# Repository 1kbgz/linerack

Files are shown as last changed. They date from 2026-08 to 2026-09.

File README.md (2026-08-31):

# LineRack

LineRack is a USB-powered audio processor with browser-configurable effect
chains. The repository contains the configurator, Seed3 firmware, hardware
designs, and developer documentation for the working prototype.

LineRack is under active development. The current hardware is suitable for
development and listening tests, not production or safety-critical use.

## Repository map

| Path | Contents |
| --- | --- |
| `src/` | React configurator, simulator, and documentation site |
| `firmware/` | Seed3 diagnostics and composite USB Audio/WebHID firmware |
| `firmware/dsp/` | Host-tested signal-processing implementation |
| `firmware/usb/` | USB transport, preset storage, display, and protocol logic |
| `hardware/` | Development BOMs, enclosure sources, and carrier-PCB work |
| `docs/` | Tutorials, how-to guides, references, and architecture explanations |

## Start developing

Install Node.js 22 or newer, pnpm 11.9, GNU Make, Git, and the Arm GNU
toolchain. Then prepare the checkout:

```sh
make develop
```

Run the configurator locally:

```sh
pnpm dev
```

Open the printed origin at `/configure`.

Run the complete verification lifecycle:

```sh
make lint
make check
make test
make build
```

See [How to set up LineRack development](docs/how-to-set-up-development.md) for
prerequisites, expected outputs, and firmware flashing.

## Developer documentation

### Tutorial

- [Build and verify the Seed3 prototype](docs/prototype-bring-up.md) follows one
  complete path from an unwired board to integrated USB Audio, WebHID, DSP,
  button, display, and persisted presets.

### How-to guides

- [Set up LineRack development](docs/how-to-set-up-development.md)
- [Verify USB Audio on Seed3](docs/usb-audio-bring-up.md)
- [Test LineRack on iPhone](docs/how-to-test-on-iphone.md)
- [Print the development enclosure](docs/how-to-print-prototype-enclosure.md)
- [Update from the repository template](docs/how-to-update-template.md)
- [Develop a new DSP plugin](docs/how-to-develop-dsp-plugin.md)
- [Deploy the website](docs/how-to-deploy-website.md)

### Reference

- [HID control protocol](docs/hid-protocol.md)
- [Preset file formats](docs/preset-file-format.md)
- [Prototype hardware](docs/prototype-hardware-reference.md)
- [Firmware build targets](docs/firmware-build-targets.md)
- [Web deployment](docs/deployment-reference.md)

### Explanation

- [Why Seed3 can handle analog input](docs/analog-input-direction.md)
- [Why DSP and display processing stay separate](docs/dsp-and-display-direction.md)

The same pages are published at [linerack.dev/docs](https://linerack.dev/docs).

## Implementation boundary

Current composite firmware provides 48 kHz stereo USB Audio playback, UAC1 host
volume and mute, WebHID configuration, four persisted presets, one-button
control, and a 128×32 OLED. Supported firmware blocks are Gain, repeatable
parametric EQ, high-pass, low-pass, noise gate, compressor, compact stereo
reverb, and Limiter. Gain and Limiter are fixed chain endpoints with eight
ordered effect positions between them.

Development USB identity `CAFE:4C52` is temporary and must not ship. Firmware
builds enforce a 126,976-byte internal-flash gate. Production USB identity,
headphone-output safety, analog-input protection, compliance, and firmware
update design remain open engineering work.

## License

Except where a file says otherwise, LineRack software, firmware, documentation,
and hardware design files are available under the
[PolyForm Noncommercial License 1.0.0](LICENSE). Personal and other
noncommercial use, modification, building, and sharing are permitted.
Commercial use or resale requires a separate written license from 1kbgz.
Third-party components remain under their own licenses.

This summary is informational. The terms in [LICENSE](LICENSE) control.

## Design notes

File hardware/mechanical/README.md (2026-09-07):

# Development enclosure reference

The active development enclosure mounts a headerless Seed3, OLED, two TRRS
breakouts, and low-profile button beneath one top shell. Components occupy two
rows without overlapping vertically. A flat bottom plate closes with four M2
screws.

## Active source

`enclosure-dev-screw.scad` accepts these `part` values:

| Value | Output |
| --- | --- |
| `base` | Flat screwed bottom plate |
| `lid` | Top shell with component mounts and connector openings |
| `assembly` | Closed component fit preview |
| `layout` | Base and lid arranged for printing |

## Dimensions

| Property | Value |
| --- | ---: |
| External length | 80 mm |
| External width | 50 mm |
| External body height | 12 mm |
| Top shell height | 10.4 mm |
| Bottom plate thickness | 1.6 mm |
| Wall and roof thickness | 1.6 mm |
| Component standoff | 1.2 mm |
| Clearance below 6.5 mm components | 1.1 mm |

External body height excludes protruding screw heads. The 80 × 50 mm footprint
provides clearance for four case bosses while keeping both audio jacks on the
end opposite USB-C.

## Component geometry

| Module | CAD envelope | Mounting |
| --- | --- | --- |
| Electro-Smith Daisy Seed3 | 51.26 × 18.24 × 6.5 mm | Headerless; roof guides, 2 × 12 × 5 mm rear support, and compressible bottom pad |
| Adafruit 4440 OLED | 33.02 × 21.59 × 6 mm | Four 2.5 mm holes on 27.94 × 16.51 mm centers |
| Two Adafruit 5764 TRRS breakouts | 17.145 × 17.78 × 6.5 mm each | Two 2.0 mm holes, 12.7 mm apart |
| Adafruit 367 button | 6 × 6 × 6 mm | Roof-seated holder with open wiring side and 7 mm finger opening |

The OLED envelope retains room for its STEMMA QT connector. Removing that
connector reduces local height but does not change case height, which is set by
the Seed3 and TRRS breakouts.

OLED and TRRS screws enter printed 1.8 mm pilot holes from inside the enclosure.
Use an M2 washer with each M2×4 component screw so the screw cannot mark the
1.6 mm top surface. Four M2×8 screws pass through the bottom plate into printed
corner bosses. The bottom plate uses 2.8 mm clearance holes to compensate for
undersized PLA holes. Printed pilots are suitable for fit testing, not repeated
production assembly.

## Generated meshes

Generated STLs live under `hardware/mechanical/generated/` and are committed
alongside the source so each revision can be printed without OpenSCAD:

- `linerack-enclosure-dev-screw-base.stl`
- `linerack-enclosure-dev-screw-lid.stl`
- `linerack-enclosure-dev-screw-layout.stl`
- `linerack-enclosure-dev-screw-assembly.stl`

Example:

```sh
openscad -o hardware/mechanical/generated/linerack-enclosure-dev-screw-layout.stl \
  -D 'part="layout"' hardware/mechanical/enclosure-dev-screw.scad
```

Print the lid with its exterior top surface on the build plate. Print the flat
base in its exported orientation. Supports should not be required.

## Archive

`old/` contains superseded mechanical sources and meshes:

- `old/compact-20.7mm/`: prior 60 × 31 × 20.7 mm friction and screw sources;
- `old/compact-23mm/`: prior 60 × 31 × 23 mm friction enclosure meshes;
- `old/enclosure-v0.scad`: original 105 × 42 mm M2/M4 source;
- `old/v0/`, `old/v0-m4/`, and `old/tests/`: original meshes and fit coupons.

## Fit status

| Property | Status |
| --- | --- |
| 80 × 50 × 12 mm enclosure | First print found undersized screw and button openings; revised export unprinted |
| Headerless Seed3 envelope | First print found rear support too small; enlarged revision unprinted |
| OLED opening and mounting pattern | Reused from verified enclosure |
| Dual TRRS mounting and openings | Second position unverified |
| Adafruit 367 holder | Switch fits; access opening enlarged to 7 mm; revised export unprinted |
| M2 screw closure | 2.4 mm clearance failed first print; revised to 2.8 mm and unverified |
| USB-C and TRRS vertical alignment | Recalculated for top-mounted components; unprinted |

This remains a development fit mule. It does not establish headphone-output
safety, strain-relief durability, drop resistance, thermal performance, or
production tolerances.

## License

These mechanical sources are available under the repository's
[PolyForm Noncommercial License 1.0.0](../../LICENSE).

Required Notice: Copyright 2025–2026 1kbgz.

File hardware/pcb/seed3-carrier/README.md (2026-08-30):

# Seed3 carrier PCB reference

This KiCad project fixes the first carrier's mechanical envelope and connector
roles. It is intentionally not a schematic, routed board, or fabrication
release.

## Mechanical contract

| Property | Current value |
| --- | --- |
| Board outline | 35 × 82 mm |
| Board thickness | 1.6 mm placeholder |
| Mounting holes | Four 2.7 mm non-plated holes on a 28 × 75 mm pattern |
| Seed3 mounting | Two 20-pin through-hole rows, 15.24 mm apart, 2.54 mm pitch |
| Seed3 orientation | USB-C faces the short edge nearest H1/H2 |
| Peripheral area | Approximately 27 mm beyond Seed3 pin span |

The Seed3 pad and fabrication geometry is transcribed from Electro-Smith's
official MIT-licensed DaisyKiCad `DAISY_SEED` footprint. Before routing or
ordering, compare the installed Seed3 revision with the current official
KiCad and STEP assets at <https://docs.daisy.audio/hardware/Seed3?embed=1>.

## Connector contract

The connector footprints reserve placement only. The future schematic must
implement these pin assignments before copper is added.

| Connector | Pin | Signal | Seed3 physical pin |
| --- | ---: | --- | ---: |
| J1 OLED | 1 | `3V3_D` | 38 |
| J1 OLED | 2 | `DGND` | 40 |
| J1 OLED | 3 | `SDA / D12` | 13 |
| J1 OLED | 4 | `SCL / D11` | 12 |
| J2 Button | 1 | `D10` | 11 |
| J2 Button | 2 | `DGND` | 40 |
| J3 Audio out | 1 | `OUT_L` | 18 |
| J3 Audio out | 2 | `OUT_R` | 19 |
| J3 Audio out | 3 | `AGND` | 20 |
| J4 Audio in, reserved | 1 | `IN_L` | 16 |
| J4 Audio in, reserved | 2 | `IN_R` | 17 |
| J4 Audio in, reserved | 3 | `AGND` | 20 |

J4 reserves mechanical space only. Its production circuit still needs input
impedance, AC coupling, filtering, ESD/overvoltage protection, and measured
headroom. See [`docs/analog-input-direction.md`](../../../docs/analog-input-direction.md).

## Before schematic capture

- Confirm socket versus permanently soldered Seed3 assembly and total height.
- Select locking connectors for OLED, button, and panel audio wiring.
- Decide whether the audio jack belongs on the carrier or enclosure panel.
- Measure USB-C, BOOT, and RESET locations against the case datum.
- Add accessible power, ground, I2C, audio, and debug test points.
- Define analog/digital ground connection from the Seed3 datasheet.
- Select ESD protection and output/load protection from measured requirements.

Do not generate Gerbers or order this board. The project contains no schematic,
net assignments, copper routing, ground planes, design rules, or manufacturing
outputs.

After placement is electrically complete, export the board assembly with
`kicad-cli pcb export step` and use that STEP file as the enclosure datum. Do
not maintain an independent second copy of the production PCB dimensions in
OpenSCAD.

## License

These PCB design files are available under the repository's
[PolyForm Noncommercial License 1.0.0](../../../LICENSE).

Required Notice: Copyright 2025–2026 1kbgz.

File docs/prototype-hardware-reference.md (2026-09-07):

# Seed3 prototype hardware reference

Verified modules, connections, and electrical boundaries for the current
LineRack development prototype. This is not a production schematic.

## Modules

| Item | Quantity | Role | Status |
| --- | ---: | --- | --- |
| Electro-Smith Daisy Seed3 | 1 | STM32 processor, USB-C, TAC5242 stereo codec, QSPI storage | Verified |
| Adafruit 0.91-inch 128×32 I2C OLED, product 4440 | 1 | Preset, EQ, visualizer, and volume display | Verified |
| STEMMA QT/Qwiic cable | 1 | OLED power and I2C | Verified |
| Normally-open momentary button | 1 | Display wake, preset selection, display mode | Basic operation verified; full gesture timing needs a repeat test |
| Adafruit TRRS jack breakout | 1 output; second required for input tests | Panel audio connection | Output verified |
| Solderless breadboard and jumpers | 1 set | Development interconnect | Verified; not shippable |
| USB-C data cable | 1 | Power, USB Audio, and WebHID | Verified on Mac and iPhone |

See `hardware/bom/dev.csv` for exact development parts and links.

## Seed3 connections

| Function | Seed3 connection | Peripheral connection |
| --- | --- | --- |
| Preset button | `D10` and `DGND` | One terminal to each |
| OLED power | `3V3 Digital` | Red STEMMA QT wire |
| OLED ground | `DGND` | Black STEMMA QT wire |
| OLED data | `D12 / SDA` | Blue STEMMA QT wire |
| OLED clock | `D11 / SCL` | Yellow STEMMA QT wire |
| Stereo input left | `Audio In 1`, physical pin 16 | Jack `Left` |
| Stereo input right | `Audio In 2`, physical pin 17 | Jack `Right` |
| Stereo input ground | `AGND`, physical pin 20 | Jack `Ring` |
| Stereo output left | `Audio Out 1` | Jack `Left` |
| Stereo output right | `Audio Out 2` | Jack `Right` |
| Stereo output ground | `AGND` | Jack `Ring` |

LineRack's channel convention is fixed: audio channel 1 is left and audio
channel 2 is right at the codec inputs, through the DSP chain, and at the codec
outputs.

Leave TRRS terminals `Sleeve`, `LSw`, and `RSw` disconnected. The button uses
Seed3's internal pull-up and needs no external resistor.

## Button gestures

| Gesture | Behavior |
| --- | --- |
| Single press | Wake display and show current state |
| Quick double press | Activate next preset |
| Hold for 3 seconds | Cycle persistent display mode immediately |
| Hold for 10 seconds or longer | Reserved |

Preset changes temporarily show the preset view before the configured display
mode returns.

## Audio and power limits

| Property | Prototype boundary |
| --- | --- |
| Power | USB-C bus power or regulated Seed3 `VIN`; no battery |
| USB playback | UAC1, stereo, 48 kHz, signed 16-bit PCM |
| USB host volume | UAC1 master volume and mute verified on Mac; iPhone verification pending |
| Codec input | 3.6 V peak-to-peak published maximum, about 1 V RMS |
| Analog input front end | Not implemented on the prototype |
| Headphone output rating | Not established |
| USB identity | `CAFE:4C52`, development only |

Direct codec input still requires impedance definition, AC coupling, RF
filtering, protection, and clipping headroom. Direct headset output testing does
not establish safe output impedance, clean level, DC, noise, thermal behavior,
or short-circuit limits.

## Recovery controls

Seed3's onboard **RESET** control can restore audio after some host or USB
faults. **BOOT** plus **RESET** enters DFU for firmware recovery. The current
development enclosure exposes both only after opening the case.

Some 128×32 SSD1306 modules can render content about 32 pixels to the right due
to a controller column-offset mismatch. Record the module and behavior before
changing display code; the fault does not affect audio or HID control.

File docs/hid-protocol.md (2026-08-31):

# LineRack HID control protocol

## Scope

This protocol transfers configuration and status data between a LineRack device
and a host configurator. USB Audio Class carries audio separately. Protocol
version 1 uses CBOR messages split across fixed-size USB HID reports.
Objects are encoded as standard CBOR maps; implementation-specific record or
string-packing extensions are not permitted.

## HID interface

| Property | Value |
| --- | --- |
| Usage page | `0xFF00` (vendor-defined) |
| Usage | `0x01` |
| Report ID | None (`0` in WebHID calls and events) |
| Input report | 64 octets |
| Output report | 64 octets |
| Interrupt IN endpoint | `0x81` on current Seed3 composite firmware |
| Interrupt OUT endpoint | `0x02` on current Seed3 composite firmware |

The report descriptor deliberately omits a report ID. Full-speed USB interrupt
endpoints allow at most 64 octets per packet; a numbered 64-octet report would
require an invalid 65-octet packet once its report ID is included.

The USB vendor ID and product ID are not assigned by this protocol. Host
software must supply an explicit device filter containing the IDs selected for
the development board or production hardware.

The endpoint addresses are implementation details rather than framing fields.
Seed3 requires HID IN on endpoint 1 for reliable completion dispatch; endpoint
`0x82` delivered only the first report of a multi-report response during target
testing.

## Report frame

All multibyte integers use little-endian byte order.

| Offset | Size | Field | Value |
| ---: | ---: | --- | --- |
| 0 | 2 | Magic | ASCII `LR` (`0x4C 0x52`) |
| 2 | 1 | Protocol version | `1` |
| 3 | 1 | Message kind | See message kinds |
| 4 | 1 | Command | See commands |
| 5 | 1 | Reserved | `0` when sent; ignored when received |
| 6 | 2 | Request ID | Host-assigned correlation ID |
| 8 | 2 | Chunk index | Zero-based index |
| 10 | 1 | Chunk count | Total reports in logical message |
| 11 | 1 | Payload length | CBOR bytes present in this report, `0`–`52` |
| 12 | 52 | Payload area | CBOR fragment followed by zero padding |

A logical message contains between 1 and 255 reports. Its maximum encoded CBOR
payload is 13,260 octets. All reports in one message have identical message
kind, command, request ID, and chunk count. The receiver assembles fragments by
chunk index and decodes CBOR only after every fragment arrives.

Current Seed3 firmware accepts request payloads up to the framing maximum and
allocates 8,192 octets for an encoded response. A response that exceeds that
buffer is replaced by an error response.

## Message kinds

| Value | Name | Direction | Meaning |
| ---: | --- | --- | --- |
| 1 | Request | Host to device | Command invocation |
| 2 | Response | Device to host | Successful result |
| 3 | Event | Device to host | Unsolicited state change |
| 4 | Error | Device to host | Rejected or failed request |

A response or error repeats its request's command and request ID. Request ID
`0` is reserved for events. Host requests use IDs `1` through `65535` and must
not reuse an ID while its request is outstanding. The browser client serializes
commands because current firmware processes one request transaction at a time.
Firmware abandons an incomplete request after approximately three seconds of
inactivity so a lost HID fragment cannot wedge later commands.

An error payload is a CBOR map with a required text `message` field:

```text
{ "message": "Preset is incompatible" }
```

## Commands

Payload type names refer to the TypeScript definitions in `src/device.ts` and
`src/presets.ts`. Empty requests encode an empty CBOR map.

| Value | Command | Request payload | Response payload |
| ---: | --- | --- | --- |
| 1 | `Hello` | `{ client: string, protocolVersion: number }` | `{ capabilities: DeviceCapabilities, status: DeviceStatus }` |
| 2 | `ReadPresets` | `{}` | `PresetFile` |
| 3 | `WritePresets` | `PresetFile` | Stored `PresetFile` |
| 4 | `ActivateSlot` | `{ slotNumber: number }` | `DeviceStatus` |
| 5 | `GetStatus` | `{}` | `DeviceStatus` |
| 6 | `CyclePreset` | `{}` | `DeviceStatus` |
| 7 | `StatusChanged` | Not a request | `DeviceStatus` event |
| 8 | `WakeDisplay` | `{}` | `DeviceStatus` |

`DeviceStatus` contains `connected`, `activeSlot`, and an optional live
`diagnostics` map with `usbPackets`, `bufferFillFrames`, `underruns`, and
`overruns`. Diagnostic counters reset on device restart. Clients should tolerate
firmware that omits this additive field.

`WritePresets` is atomic at the logical-message level. Firmware validates the
complete document before replacing stored presets. It returns the stored
document on success or an error without changing the prior document.

`CyclePreset` follows the same slot order as a physical-button double tap. The
device emits `StatusChanged` whenever the active slot changes, including changes
caused by the physical button. Command responses still contain the resulting
status so they do not depend on event delivery.

`WakeDisplay` restarts the OLED inactivity timer without changing or persisting
the setup. Firmware advertises support as `DeviceCapabilities.displayWake`.
The browser coalesces rapid edits before sending it so slider drags cannot flood
the serialized HID request queue.

## Device data

`DeviceStatus` has this shape:

```text
{
  "connected": true,
  "activeSlot": 1
}
```

`DeviceCapabilities` declares product and firmware identity plus preset limits
and available plugin definitions. `PresetFile` carries engine metadata, a
device-wide display preference, and the four named slots with their ordered
plugin instances:

```text
{
  "format": "linerack-presets",
  "schemaVersion": 1,
  "engine": { "sampleRate": 48000, "channels": 2 },
  "display": { "defaultMode": "preset", "blankingEnabled": true },
  "routing": {
    "sourceMode": "usb",
    "usbTrimDb": 0,
    "analogTrimDb": 0
  },
  "slots": [ ... ]
}
```

`display.defaultMode` is `preset`, `eq-response`, or `visualizer`.
`display.blankingEnabled` defaults to `true`; current firmware turns the OLED
off after 20 seconds and wakes it on a physical button press or successful
`WritePresets`. When `displayWake` is supported, browser edits also wake it
without applying the draft. The browser treats a missing `display` map or blanking field
from preceding protocol-v1 firmware as Preset mode with blanking enabled, so it
can connect to and upgrade that hardware. Firmware advertises disable support as
`DeviceCapabilities.displayBlanking` and must reject other documents
incompatible with its declared capabilities.

`routing.sourceMode` is `usb`, `analog`, or `mix`. Trims range from -24 to
0 dB in 0.5 dB steps. Mixed mode requires both trims at or below -6.5 dB.
Firmware advertises supported values in `DeviceCapabilities.sourceModes`.
The browser treats a missing `routing` map from older protocol-v1 firmware as
USB-only with 0 dB trims.

Current firmware-source limits are:

| Property | Value |
| --- | ---: |
| Preset slots | 4 |
| Maximum name storage | 12 supported ASCII characters plus terminator |
| Blocks per preset | 10 total |
| Audio format | 48 kHz, two channels |

Each preset contains exactly one Gain at index 0 and exactly one Limiter at the
final index. Up to eight middle blocks may be reordered or repeated. Gain and
Limiter may be disabled but cannot be removed or moved. The device validates
all four presets before storing or activating a replacement bank.

### Plugin contract limits

| Property | Current limit |
| --- | ---: |
| Decoded plugin ID | 19 CBOR text bytes |
| Plugin version | `1` |
| Parameters stored per block | 5 |
| Decoder parameter-ID mask | 16 bits; 15 IDs assigned |
| Plugin instances per preset | 10, including Gain and Limiter |

The parameter-ID mask is shared across the firmware catalogue, not reset per
plugin. Unknown IDs, versions, and parameter names are rejected.

Advertised firmware plugins are:

| Plugin ID | Parameters |
| --- | --- |
| `gain` | `gainDb` (-24 to +12 dB) |
| `parametric-eq` | `frequencyHz` (20–20,000 Hz), `gainDb` (-18 to +18 dB), `q` (0.1–18) |
| `high-pass` | `cutoffHz` (20–20,000 Hz), `slopeDbPerOct` (12 or 24) |
| `low-pass` | `cutoffHz` (20–20,000 Hz), `slopeDbPerOct` (12 or 24) |
| `noise-gate` | `thresholdDb` (-80–0 dB), `attackMs` (0.1–100), `holdMs` (0–500), `releaseMs` (5–2,000), `rangeDb` (-80–0 dB) |
| `compressor` | `thresholdDb` (-60–0 dB), `ratio` (1–20), `attackMs` (0.1–200), `releaseMs` (10–2,000) |
| `reverb` | `size` (0–100%), `damping` (0–100%), `mix` (0–100%) |
| `limiter` | `ceilingDb` (-12–0 dB) |

All current plugin definitions use version `1`. Unknown plugin IDs, versions,
parameters, duplicate endpoint plugins, misplaced endpoints, out-of-range
values, and chains longer than ten blocks are rejected.

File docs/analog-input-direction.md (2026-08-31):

# Why Seed3 does not need an external audio ADC

Seed3's existing codec can digitize LineRack's analog stereo source. An extra
ADC or codec breakout would duplicate that function without solving the analog
front-end work a product still needs.

## The codec boundary

Seed3 uses TI's TAC5242, which contains two ADC and two DAC channels. Seed3
exposes the codec inputs as `AUDIO IN L` and `AUDIO IN R` on physical pins 16
and 17, with analog ground on pin 20. Their published maximum is 3.6 V
peak-to-peak, about 1 V RMS. They are audio inputs, not STM32 control ADC pins.

Firmware can select USB, analog, or a trimmed mix before routing stereo samples
through the active effect chain and codec outputs. Native tests cover this path;
physical analog-input verification still requires a second input jack.

## Why a carrier front end is still required

An onboard ADC does not make a panel jack production-ready. The carrier must
define:

- Input impedance and connector mapping
- AC coupling and DC bias behavior
- RF filtering and transient protection
- Clipping headroom
- Line-level or instrument-level input behavior

Daisy's line-input reference uses about 20 kΩ input impedance plus op-amp,
filtering, and coupling stages. Its instrument reference uses 1 MΩ. A stereo
line adapter and mono instrument adapter may share the DSP interface, but they
should not share an unspecified analog circuit.

## Source mixing and headroom

USB-only and analog-only modes select one stereo source. Mix mode sums both
sources after independent trims from -24 to 0 dB in 0.5 dB steps. Firmware
requires both mix trims at or below -6.5 dB so correlated full-scale sources do
not clip before DSP.

Analog-only describes the signal source, not the power source. Seed3 still
needs USB-C power or regulated `VIN`; a phone charger or ordinary USB power bank
is enough for a battery-free prototype.

## Tradeoff

Reusing TAC5242 keeps the prototype small and avoids another digital audio
interface. It also makes the custom carrier responsible for input safety and
signal conditioning. That trade is appropriate for the current line-level
prototype, but it does not settle a future instrument-input design.

## Sources

- [Daisy Seed3 documentation](https://docs.daisy.audio/hardware/Seed3)
- [Daisy Seed3 datasheet](https://daisy.nyc3.cdn.digitaloceanspaces.com/products/seed3/Daisy_Seed3_datasheet.pdf)
- [TI TAC5242 product page](https://www.ti.com/product/TAC5242)

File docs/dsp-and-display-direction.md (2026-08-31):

# How DSP and display state fit together

LineRack has two related but independent graphs: an audio graph that must meet
real-time deadlines, and a display graph that observes state without blocking
audio. Keeping that boundary explicit lets the browser, firmware, and future
hardware evolve without turning UI work into audio risk.

## Two data paths

```text
USB or analog audio
  -> source routing and trim
  -> fixed Gain
  -> up to eight ordered effects
  -> fixed Limiter
  -> host volume and mute
  -> codec output

audio meters + active preset + host volume + display preference
  -> bounded snapshots
  -> display renderer
  -> 128×32 OLED
```

The audio callback performs no HID parsing, flash writes, I2C transfers, or
dynamic allocation. Control code validates a complete setup and prepares a
staging processor bank. Firmware swaps that bank at a safe boundary instead of
mutating active processors during playback.

## A versioned effect contract

Each plugin instance stores an ID, plugin version, bypass state, and named
parameters. The device advertises its supported plugins and limits through the
HID capability response. The browser uses that response as authoritative.

This contract separates three concerns:

- Firmware implements deterministic, bounded processors.
- The configurator edits chains and validates device compatibility.
- Preset recipes provide useful parameter values without becoming new DSP
  types.

A listening label such as “movie” or “live room” is therefore a recipe built
from ordinary filters, dynamics, and reverb. Firmware does not need a special
movie-mode processor.

Current Seed3 firmware advertises Gain, Parametric EQ, High-pass, Low-pass,
Noise Gate, Compressor, Reverb, and Limiter. Gain and Limiter are fixed at the
chain endpoints and may be bypassed. The eight middle positions may contain
repeated or reordered supported effects.

## Resource model

The main constraints differ by resource:

| Resource | Constraint | Design response |
| --- | --- | --- |
| Internal flash | Composite image must remain within 126,976 bytes | Keep the build gate; move to the supported bootloader/SRAM path before exceeding it |
| Real-time CPU | Every stereo frame has a fixed deadline | Use bounded algorithms and measure complete worst-case chains |
| Processor state | Active and staging chains coexist during updates | Allocate fixed banks once; swap prepared state |
| Delay memory | Reverb needs much more history than filters | Keep delay lines in external SDRAM with fixed per-block workspaces |
| USB clock drift | Host and codec clocks are independent | Bound ring fill with adaptive resampling |

This model favors algorithmic reverb over convolution for the current device.
Convolution would add impulse transfer, storage, partitioned FFT work, and a
larger compatibility surface. It can remain a separate future processor rather
than complicating the compact reverb.

## Filter and dynamics behavior

Parametric EQ and pass filters use direct-form biquads with coefficients
prepared outside the audio callback. Repeated Parametric EQ instances provide
multiple bands without a separate fixed-band firmware type. High-pass and
low-pass filters support 12 or 24 dB/octave slopes by changing cascade depth.

Gate and compressor detectors are stereo linked so one channel cannot open or
compress independently and pull the image sideways. Limiter remains the final
safety ceiling. Bypass must preserve a stable chain and avoid discontinuities
when practical.

## Analysis and rendering

Visualization is lower priority than uninterrupted audio. Audio code publishes
small, bounded snapshots such as peak level, spectrum bins, active preset, and
host volume. Display code consumes the latest complete snapshot and may skip a
frame when busy.

The 128×32 OLED supports three persistent modes:

- **Preset**: slot number and short name
- **EQ Response**: current chain response
- **Visualizer**: live left and right level meters

Temporary events override the persistent mode. A preset change shows Preset;
a host volume change shows its percentage. After the timeout, the configured
mode returns. Display blanking is device-wide, defaults to 20 seconds, and
wakes on button input, host volume, browser edits, or an applied setup.

OLED I2C work occurs outside the audio callback. Display failure must not stop
audio or control traffic.

## Why configuration stays in the browser

The hosted configurator owns interaction-heavy work: arranging processors,
drawing response previews, managing recipes, and importing or exporting setup
files. Firmware owns validation, persistence, processing, and simple device UI.
This keeps the embedded surface small while allowing the interface to improve
without reflashing every unit.

The boundary is versioned rather than implicit. A setup is accepted only when
its engine format, chain shape, plugin versions, and parameter values match the
connected device's advertised capabilities.

## Related documentation

- [HID control protocol](hid-protocol.md)
- [Preset file format](preset-file-format.md)
- [Analog input architecture](analog-input-direction.md)
- [Verify USB Audio on Seed3](usb-audio-bring-up.md)

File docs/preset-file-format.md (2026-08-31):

# LineRack preset file format

LineRack setup and shared-preset files are UTF-8 JSON documents. Schema version
1 uses two root formats:

| Content | Format identifier | Conventional suffix |
| --- | --- | --- |
| Complete device setup | `linerack-presets` | `.linerack.json` |
| One shared preset | `linerack-preset` | `.linerack-preset.json` |

## Root object

| Field | Type | Required | Value |
| --- | --- | --- | --- |
| `format` | string | yes | `linerack-presets` |
| `schemaVersion` | integer | yes | `1` |
| `engine` | object | yes | Audio engine metadata |
| `display` | object | accepted as optional | Device-wide display settings |
| `routing` | object | accepted as optional | Device-wide source routing |
| `slots` | array | yes | One or more preset slots |

Missing `display` and `routing` objects are accepted for compatibility with
older version 1 files. Normalization supplies the current defaults. Exported
files always contain both objects.

## Engine object

| Field | Type | Constraint |
| --- | --- | --- |
| `sampleRate` | integer | Positive; current hardware requires `48000` |
| `channels` | integer | Positive; current hardware requires `2` |

## Display object

| Field | Type | Constraint | Default |
| --- | --- | --- | --- |
| `defaultMode` | string | `preset`, `eq-response`, or `visualizer` | `preset` |
| `blankingEnabled` | boolean | `true` or `false` | `true` |

`defaultMode` is the display shown after temporary preset-change feedback has
expired. Current firmware blanks the OLED after 20 seconds when
`blankingEnabled` is `true`.

## Routing object

| Field | Type | Constraint | Default |
| --- | --- | --- | --- |
| `sourceMode` | string | `usb`, `analog`, or `mix` | `usb` |
| `usbTrimDb` | number | -24 through 0 in 0.5 dB steps | `0` |
| `analogTrimDb` | number | -24 through 0 in 0.5 dB steps | `0` |

Mixed routing requires both trims to be -6.5 dB or lower. This preserves
headroom when correlated full-scale USB and analog sources are summed.

## Preset slot object

| Field | Type | Constraint |
| --- | --- | --- |
| `number` | integer | Positive and unique |
| `name` | string | Non-empty |
| `plugins` | array | Ordered plugin instances |

Current hardware requires exactly four slots numbered 1 through 4. Names may
contain ASCII letters, numbers, spaces, period, question mark, and hyphen. The
encoded name length is limited to 12 UTF-8 bytes.

## Plugin instance object

| Field | Type | Constraint |
| --- | --- | --- |
| `id` | string | Non-empty instance identity; normally a UUID |
| `pluginId` | string | ID advertised by the target device |
| `pluginVersion` | integer | Positive and supported by the target device |
| `enabled` | boolean | Processing bypass state |
| `parameters` | object | Parameter IDs mapped to scalar values |

Parameter values may be numbers, booleans, or strings at the file-validation
boundary. Device compatibility requires every advertised numeric parameter,
rejects unknown parameter IDs, and enforces the advertised range.

Current hardware allows ten plugin instances per slot. One `gain` instance is
required at index 0 and one `limiter` instance is required at the final index.
The eight positions between them contain repeatable or reordered effects.

## Shared preset object

A shared-preset document carries one named chain without a slot number or
device-wide display and routing settings.

| Field | Type | Required | Value |
| --- | --- | --- | --- |
| `format` | string | yes | `linerack-preset` |
| `schemaVersion` | integer | yes | `1` |
| `engine` | object | yes | Same shape as a complete setup |
| `preset` | object | yes | `name` and `plugins` from a preset slot |

The configurator assigns an imported shared preset to the selected slot. Device
compatibility checks still apply to its engine, chain, and parameters.

```json
{
  "format": "linerack-preset",
  "schemaVersion": 1,
  "engine": { "sampleRate": 48000, "channels": 2 },
  "preset": {
    "name": "Everyday",
    "plugins": [
      {
        "id": "1e059750-95ee-4d3f-9ef7-e6257ce78cd5",
        "pluginId": "gain",
        "pluginVersion": 1,
        "enabled": true,
        "parameters": { "gainDb": 0 }
      },
      {
        "id": "0d2af531-f075-4d23-9d36-941f95f5ea3a",
        "pluginId": "limiter",
        "pluginVersion": 1,
        "enabled": true,
        "parameters": { "ceilingDb": -1 }
      }
    ]
  }
}
```

## Complete setup example

```json
{
  "format": "linerack-presets",
  "schemaVersion": 1,
  "engine": { "sampleRate": 48000, "channels": 2 },
  "display": { "defaultMode": "eq-response", "blankingEnabled": true },
  "routing": { "sourceMode": "usb", "usbTrimDb": 0, "analogTrimDb": 0 },
  "slots": [
    {
      "number": 1,
      "name": "Everyday",
      "plugins": [
        {
          "id": "1e059750-95ee-4d3f-9ef7-e6257ce78cd5",
          "pluginId": "gain",
          "pluginVersion": 1,
          "enabled": true,
          "parameters": { "gainDb": 0 }
        },
        {
          "id": "0d2af531-f075-4d23-9d36-941f95f5ea3a",
          "pluginId": "limiter",
          "pluginVersion": 1,
          "enabled": true,
          "parameters": { "ceilingDb": -1 }
        }
      ]
    }
  ]
}
```

The abbreviated example is structurally valid but incompatible with current
hardware because current hardware requires all four preset slots.

## Compatibility boundary

JSON validation establishes document shape. Device compatibility additionally
checks slot count, engine format, routing support, display features, plugin
catalog, plugin versions, endpoint positions, parameter ranges, and chain
length. The connected device's advertised capabilities are authoritative.

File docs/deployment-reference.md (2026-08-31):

# Web deployment reference

LineRack ships as one static Vite application. It has no server-side
application code or database.

## Build contract

| Property | Value |
| --- | --- |
| Package manager | pnpm 11.9 |
| Node.js | 22 or newer |
| Install command | `pnpm install --frozen-lockfile` |
| Build command | `pnpm build` |
| Output directory | `dist` |
| Required environment variables | None |

## Public routes

| Route | Content |
| --- | --- |
| `/` | Site landing page |
| `/configure` | Hardware configurator and simulator |
| `/product` | Device overview and availability status |
| `/docs` | Developer documentation index |
| `/docs/<slug>` | Developer documentation page |

`public/_redirects` becomes `dist/_redirects`. Its `/* /index.html 200` rule
allows the client to resolve deep links.

## Cloudflare Pages

| Setting | Value |
| --- | --- |
| Production branch | `main` |
| Production URL | `https://linerack.dev` |
| Framework | Vite or equivalent manual settings |
| Build command | `pnpm build` |
| Build output directory | `dist` |
| Root directory | Repository root |
| Node compatibility | Node.js 22 |

The `1kbgz/terraform` repository owns the `linerack` Pages project, custom
domain, and DNS record. The LineRack workflow uploads its tested `dist` artifact
with Wrangler Direct Upload after web and firmware jobs pass on `main`.
Cloudflare Git integration is not used.

Required GitHub Actions values:

| Kind | Name | Value |
| --- | --- | --- |
| Repository variable | `CLOUDFLARE_ACCOUNT_ID` | Account containing the `linerack` Pages project |
| Repository secret | `CLOUDFLARE_API_TOKEN` | Token with Account / Cloudflare Pages / Edit |

The deployment job remains skipped when `CLOUDFLARE_ACCOUNT_ID` is absent.
Credential values are intentionally omitted from this repository and its
documentation. Only their GitHub Actions names form part of the deployment
contract.

## Repository automation

The Python Project Templates Copier Update GitHub App reads
`.copier-answers.yaml`. The Python Templates Automerge GitHub App handles
label-controlled pull-request automerge. Neither app participates in site
deployment.

## Browser boundary

Static landing, product, and documentation pages work in current standards-
based browsers. Hardware configuration additionally requires desktop Chromium,
a secure HTTPS origin or recognized local origin, and explicit WebHID device
authorization.

Playback and stored preset selection do not depend on the site after a setup is
written. iPhone playback uses USB Audio; mobile Safari configuration is not
supported.

## External services

The application has no analytics, accounts, payments, email, waitlist, or
remote preset service.

## Platform references

- [Cloudflare Pages Vite deployment](https://developers.cloudflare.com/pages/framework-guides/deploy-a-vite3-project/)
- [Cloudflare Pages Direct Upload](https://developers.cloudflare.com/pages/how-to/use-direct-upload-with-continuous-integration/)
- [Cloudflare Pages redirects](https://developers.cloudflare.com/pages/configuration/redirects/)

## See also

- [How to deploy the website](how-to-deploy-website.md)

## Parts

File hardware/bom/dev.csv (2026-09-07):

item_id | configuration | quantity | manufacturer | model | manufacturer_part_number | description | selection_status | verification | product_url | notes
DEV-001 | all | 1 | Electro-Smith | Daisy Seed3 | Daisy Seed3 | Audio DSP module with USB-C and stereo codec | selected | Verified on Mac and iPhone | https://electro-smith.com/pages/the-daisy-seed | 12 mm enclosure requires headers removed
DEV-002 | all | 1 | Adafruit | Monochrome 0.91-inch 128x32 I2C OLED | 4440 | SSD1306 OLED with STEMMA QT | selected | Display and blanking verified | https://www.adafruit.com/product/4440
DEV-003 | all | 1 | Adafruit | STEMMA QT to male-header cable 150 mm | 4209 | Four-wire OLED power and I2C cable | selected | Verified | https://www.adafruit.com/product/4209 | Red 3V3; black ground; blue SDA; yellow SCL
DEV-004 | all | 1 | Adafruit | Tactile Button Switch 6 mm | 367 | Low-profile normally-open preset button | selected | Electrical behavior verified with larger equivalent | https://www.adafruit.com/product/367 | Physical holder remains unverified
DEV-005 | all | 2 | Adafruit | TRRS Jack Breakout Board | 5764 | 3.5 mm stereo input and output breakouts | selected | Stereo output verified; input unverified | https://www.adafruit.com/product/5764 | Sleeve LSw and RSw unused
DEV-006 | all | 1 | User supplied | USB-C data cable |  | Power USB Audio and WebHID cable | selected | Verified on current hosts |  | Must carry data and required bus power
DEV-007 | breadboard | 1 | Adafruit | Full Sized Premium Breadboard 830 Tie Points | 239 | Solderless development interconnect | reference equivalent | Current user-supplied breadboard verified | https://www.adafruit.com/product/239 | Equivalent breadboard is acceptable
DEV-008 | breadboard | 1 | Adafruit | Premium Male/Male Jumper Wires 40 x 75 mm | 759 | Breadboard jumpers | reference equivalent | Equivalent jumpers verified | https://www.adafruit.com/product/759
DEV-009 | enclosed | 1 | LineRack | Development screw enclosure | enclosure-dev-screw | Printed top shell and bottom plate | selected | First 80 x 50 x 12 mm print found undersized screw and button openings; revised export unprinted | https://github.com/1kbgz/linerack/blob/main/hardware/mechanical/enclosure-dev-screw.scad | PLA fit-test part
DEV-010 | enclosed | 8 | maierke | M2 x 4 mm stainless Phillips pan-head machine screws | B0FY11XH56 | OLED and dual TRRS mounting screws | selected | Unverified in revised enclosure | https://www.amazon.com/dp/B0FY11XH56 | 50 included in assortment; use an M2 washer where available to protect the 1.6 mm top surface
DEV-011 | enclosed-screw | 4 | maierke | M2 x 8 mm stainless Phillips pan-head machine screws | B0FY11XH56 | Case closure screws | selected | Unverified in revised enclosure | https://www.amazon.com/dp/B0FY11XH56 | 50 included in same assortment; test carefully in PLA pilots and avoid repeated over-tightening
DEV-012 | enclosed | 1 | Adafruit | Silicone Cover Stranded-Core Wire 30 AWG | 2051 | Point-to-point hookup wire | reference equivalent | Current soldered wiring verified | https://www.adafruit.com/product/2051 | Use multiple colors
DEV-013 | enclosed | 1 | Generic | Heat-shrink tubing assortment |  | Joint insulation and strain relief | required | Unverified
DEV-014 | enclosed | 1 | Generic | PLA filament 1.75 mm |  | Printed enclosure material | selected | Prior enclosure printed successfully |  | Printer-specific

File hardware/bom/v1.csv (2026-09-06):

item_id | subsystem | quantity | manufacturer | model | manufacturer_part_number | description | selection_status | validation_required | product_url | notes
V1-001 | compute and audio | 1 | Electro-Smith | Daisy Seed3 | Daisy Seed3 | DSP module and codec | provisional | Supply lifecycle unit cost thermal and production-programming review | https://electro-smith.com/pages/the-daisy-seed | V1 begins as a Seed3 carrier rather than a custom processor board
V1-002 | carrier PCB | 1 | LineRack | Seed3 carrier v1 | custom | Custom narrow interconnect PCB | in design | Schematic routing DRC assembly fit and fabrication review | https://github.com/1kbgz/linerack/tree/main/hardware/pcb/seed3-carrier | Current KiCad project is placement-only and must not be fabricated
V1-003 | display | 1 | Adafruit | Monochrome 0.91-inch 128x32 I2C OLED | 4440 | Development display reference | provisional | Cost availability mounting cable bend and burn-in review | https://www.adafruit.com/product/4440 | Decide module versus bare production display
V1-004 | user control | 1 | TBD | Low-profile normally-open momentary switch | TBD | Preset button | tbd | Actuation force cycle life mounting and sourcing review |  | Adafruit 367 is development reference only
V1-005 | audio output | 1 | TBD | 3.5 mm stereo jack | TBD | Panel or PCB-mounted output | tbd | Contact mapping insertion life strain relief and load testing |  | Adafruit 5764 is development reference only
V1-006 | audio input | 1 | TBD | 3.5 mm stereo line-input jack | TBD | Optional analog stereo input | tbd | Input use case impedance protection headroom and routing tests |  | Do not populate until analog front end is defined
V1-007 | analog input front end | 1 | TBD | Input coupling filtering and protection network | TBD | Codec input conditioning | tbd | AC coupling RF ESD overvoltage clipping and noise characterization
V1-008 | analog output stage | 1 | TBD | Output protection or headphone amplifier | TBD | Safe analog output stage | tbd | DC impedance clean level noise heat short-circuit and representative-load characterization
V1-009 | internal interconnect | 1 | TBD | Locking wire-to-board connectors | TBD | OLED button and any panel-jack connections | tbd | Pinout current rating retention cable bend and assembly review
V1-010 | enclosure | 1 | LineRack | Enclosure v1 | custom | Printed enclosure derived from final PCB STEP | tbd | Fit thermal drop strain relief service access and printer tolerance tests |  | Do not freeze against independent placeholder board geometry
V1-011 | fasteners | 1 | TBD | Case and component fastener set | TBD | Production assembly hardware | tbd | Material torque pull-out cycle and serviceability tests |  | Select after enclosure material and boss geometry
V1-012 | USB identity | 1 | TBD | Production VID PID and descriptors | TBD | Distributable USB identity | tbd | Allocation descriptor compatibility and updater recovery validation |  | Development CAFE:4C52 identity cannot ship

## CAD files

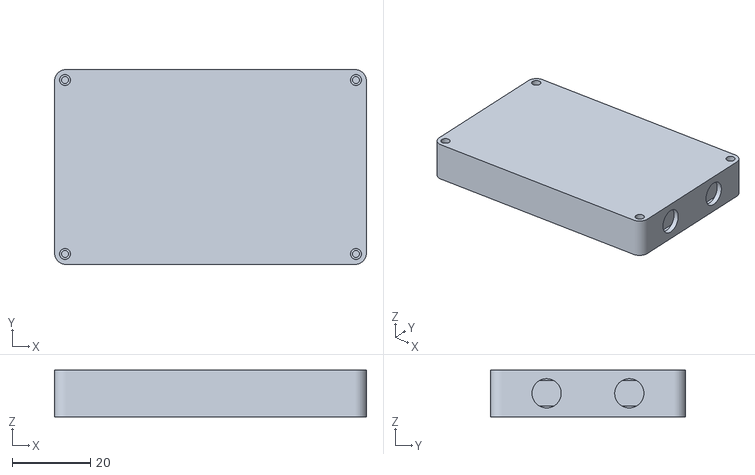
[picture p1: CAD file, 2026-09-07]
hardware/mechanical/generated/linerack-enclosure-dev-screw-assembly.stl
80.0 x 50.0 x 12.0

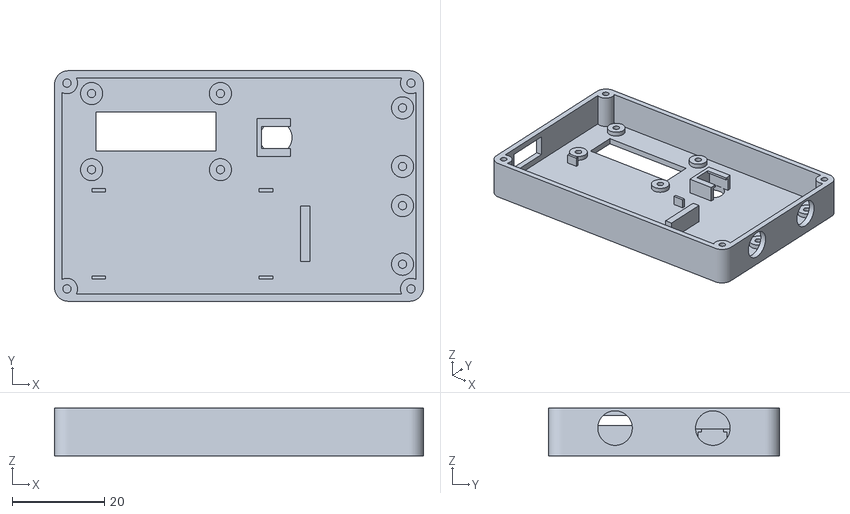
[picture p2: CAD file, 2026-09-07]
hardware/mechanical/generated/linerack-enclosure-dev-screw-lid.stl
80.0 x 50.0 x 10.4

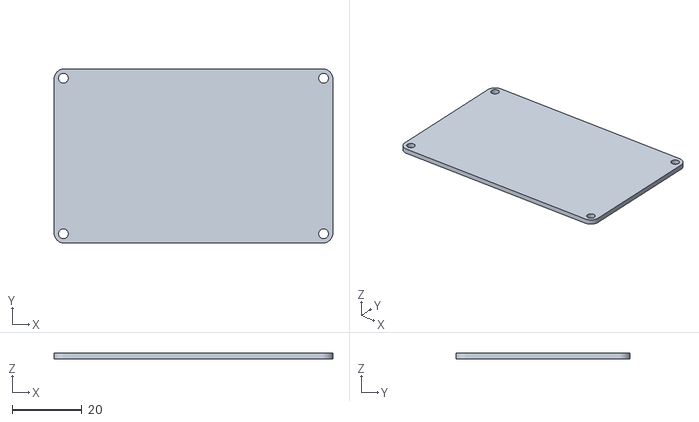
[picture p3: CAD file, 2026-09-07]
hardware/mechanical/generated/linerack-enclosure-dev-screw-base.stl
80.0 x 50.0 x 1.60

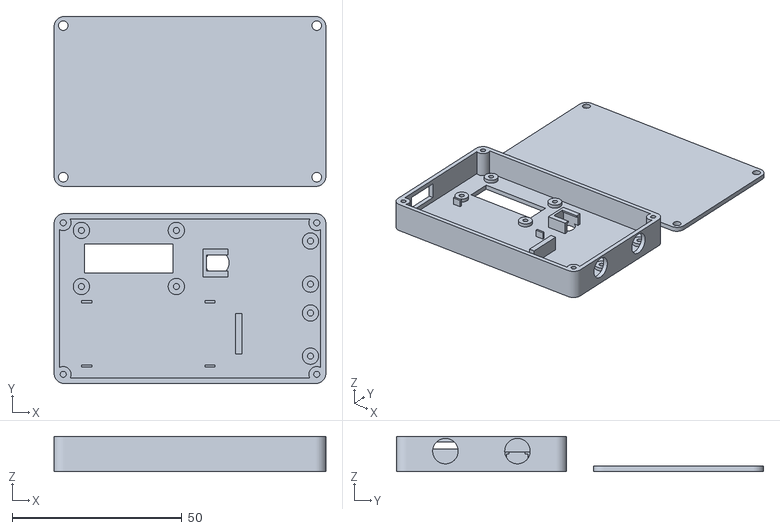
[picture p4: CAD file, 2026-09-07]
hardware/mechanical/generated/linerack-enclosure-dev-screw-layout.stl
80.0 x 108.0 x 10.4

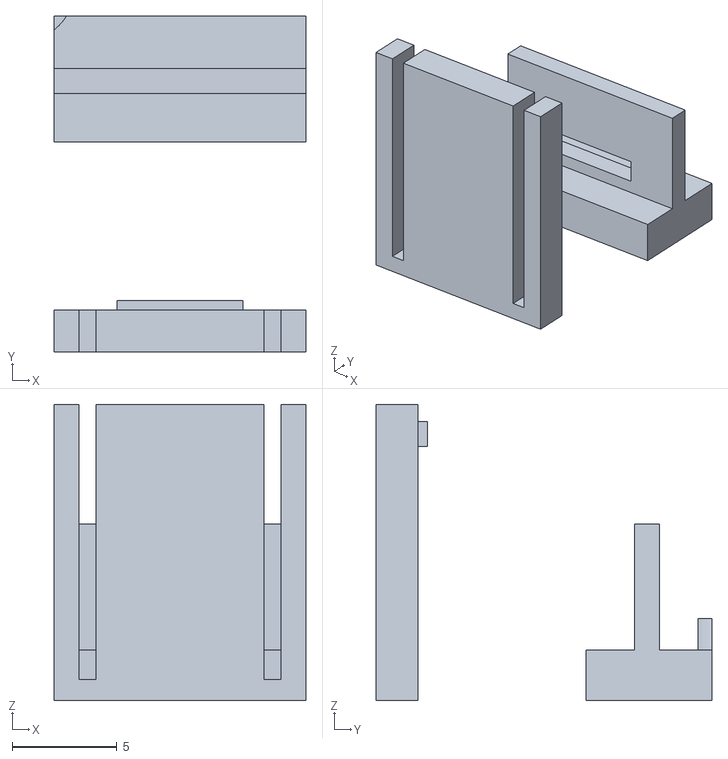
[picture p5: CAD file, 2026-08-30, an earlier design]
hardware/mechanical/old/compact-23mm/linerack-enclosure-snap-fit-test.stl
12.0 x 16.0 x 14.1

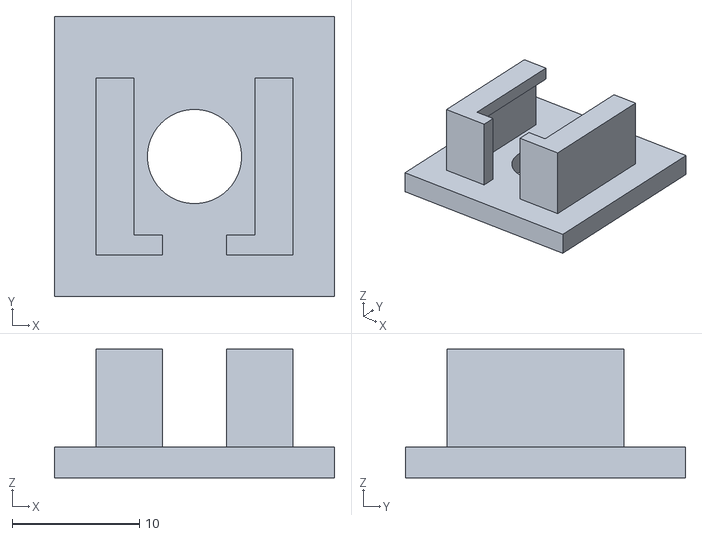
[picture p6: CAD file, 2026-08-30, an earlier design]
hardware/mechanical/old/tests/linerack-switch-fit-test.stl
22.0 x 22.0 x 10.1

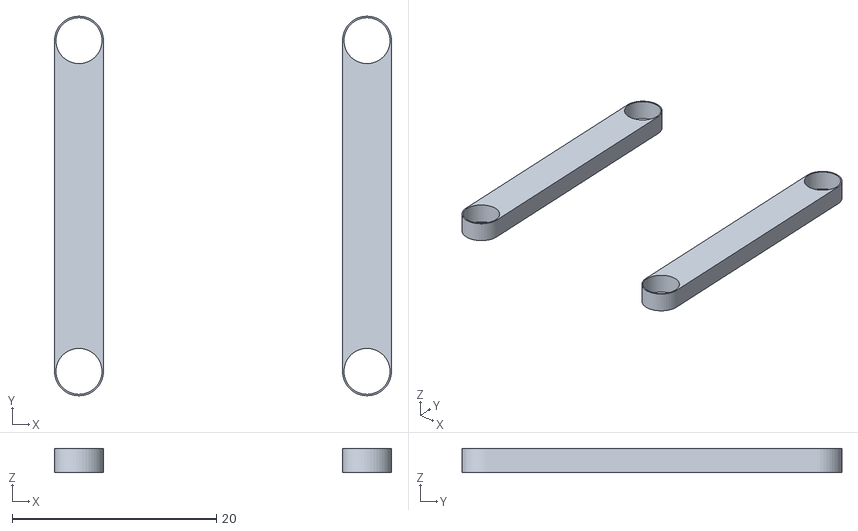
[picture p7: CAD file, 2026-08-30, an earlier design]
hardware/mechanical/old/v0-m4/linerack-enclosure-m4-oled-clamps.stl
33.0 x 37.2 x 2.40

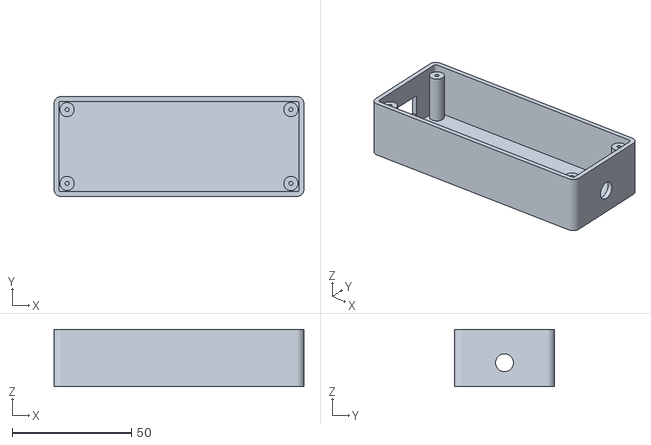
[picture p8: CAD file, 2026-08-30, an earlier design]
hardware/mechanical/old/v0/linerack-enclosure-v0-base.stl
105.0 x 42.0 x 24.0

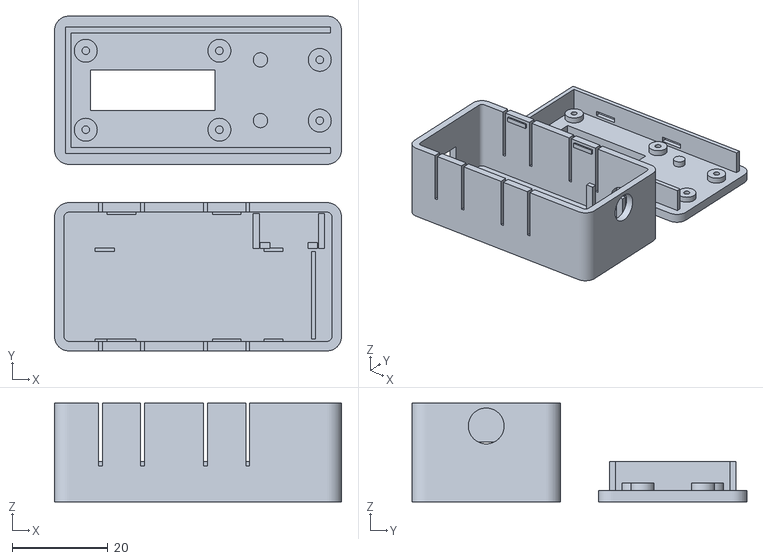
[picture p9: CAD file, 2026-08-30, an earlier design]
hardware/mechanical/old/compact-23mm/linerack-enclosure-compact-layout.stl
60.0 x 70.0 x 20.6

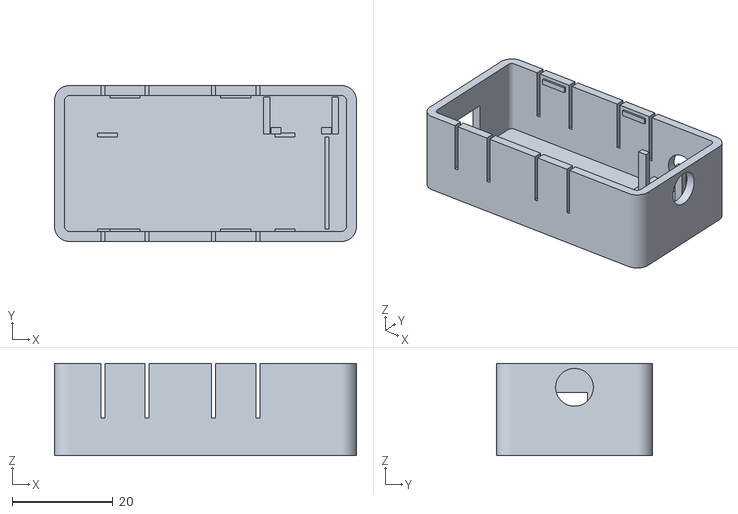
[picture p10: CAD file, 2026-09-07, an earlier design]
hardware/mechanical/old/linerack-enclosure-dev-friction-base.stl
60.0 x 31.0 x 18.3

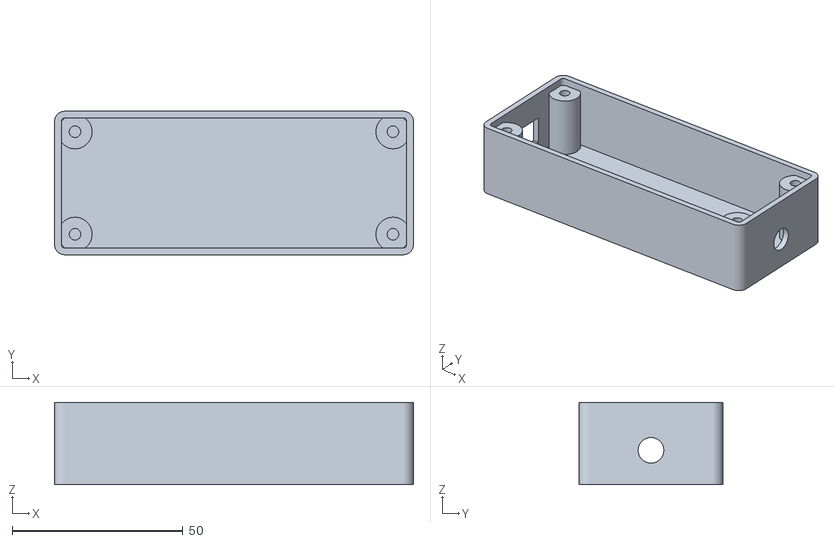
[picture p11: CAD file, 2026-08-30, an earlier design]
hardware/mechanical/old/v0-m4/linerack-enclosure-m4-base.stl
105.0 x 42.0 x 24.0

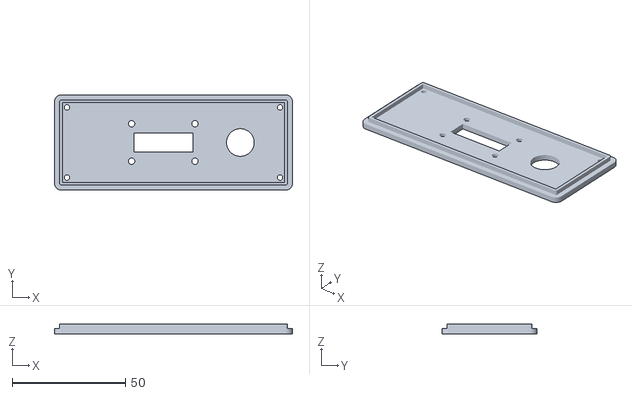
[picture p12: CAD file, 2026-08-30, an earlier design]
hardware/mechanical/old/v0/linerack-enclosure-v0-lid.stl
105.0 x 42.0 x 4.40

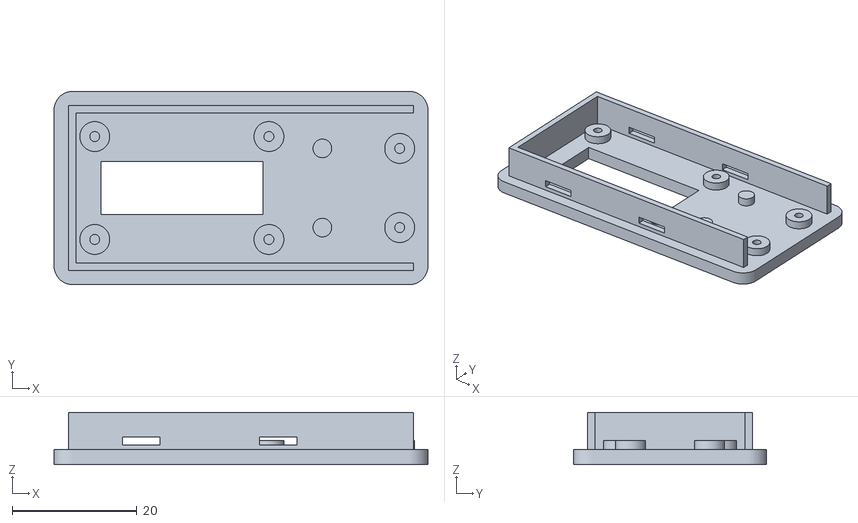
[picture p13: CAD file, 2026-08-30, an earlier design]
hardware/mechanical/old/compact-23mm/linerack-enclosure-compact-lid.stl
60.0 x 31.0 x 8.40

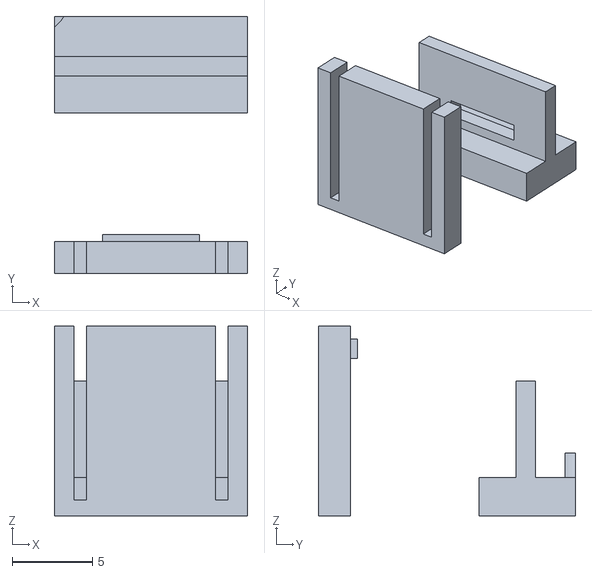
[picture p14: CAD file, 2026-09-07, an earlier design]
hardware/mechanical/old/linerack-enclosure-dev-friction-fit-test.stl
12.0 x 16.0 x 11.8

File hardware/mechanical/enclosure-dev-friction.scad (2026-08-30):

part = "layout"; // "base", "lid", "assembly", "snap-fit-test", or "layout"

$fn = 48;

outer_length = 60;
outer_width = 31;
base_height = 18.3;
lid_thickness = 2.4;
wall = 2;
floor = 2;
corner_radius = 3;

fit_clearance = 0.3;
skirt_thickness = 1.2;
skirt_depth = 6;
snap_centers = [14, 36];
snap_tab_width = 8;
snap_slot_width = 0.8;
snap_anchor_z = 7.5;
snap_engagement = 0.45;
snap_height = 1.2;
snap_nub_z = base_height - 2;

seed_envelope = [51.26, 18.24, 10];
seed_origin = [2.5, 2.5, floor];

oled_board = [33.02, 21.59, 6];
oled_origin = [4, (outer_width - oled_board[1]) / 2];
oled_hole_spacing = [27.94, 16.51];
oled_window = [26, 8.5];
oled_center = [oled_origin[0] + oled_board[0] / 2,
               oled_origin[1] + oled_board[1] / 2];

trrs_board = [17.145, 17.78, 6.5];
trrs_origin = [outer_length - wall - trrs_board[0],
               (outer_width - trrs_board[1]) / 2];
trrs_hole_x = trrs_origin[0] + 14.605;
trrs_hole_y = [trrs_origin[1] + 2.54, trrs_origin[1] + 15.24];

mount_standoff = 1.5;
mount_post_diameter = 4.8;
mount_pilot_diameter = 1.6;
mount_pilot_start = 1.2;

button_body = [12, 6, 12];
button_center = [49, outer_width - wall - button_body[1] / 2, floor + 6];
button_actuator_diameter = 7.4;
button_holder_wall = 1.3;
button_fit_clearance = 0.3;

usb_cutout = [13, 9];
usb_center_y = seed_origin[1] + seed_envelope[1] / 2;
usb_bottom_z = 3.5;

audio_cutout_diameter = 7.5;
audio_center_y = outer_width / 2;
audio_center_z = base_height - mount_standoff - trrs_board[2] / 2;

module rounded_prism(size, radius) {
    linear_extrude(height = size[2])
        offset(r = radius)
            offset(delta = -radius)
                square([size[0], size[1]]);
}

module snap_nubs() {
    for (x = snap_centers) {
        translate([x - (snap_tab_width - 2) / 2,
                   wall - 0.1,
                   snap_nub_z])
            cube([snap_tab_width - 2,
                  snap_engagement + 0.1,
                  snap_height]);
        translate([x - (snap_tab_width - 2) / 2,
                   outer_width - wall - snap_engagement,
                   snap_nub_z])
            cube([snap_tab_width - 2,
                  snap_engagement + 0.1,
                  snap_height]);
    }
}

module snap_slot_cuts() {
    for (x = snap_centers)
        for (side = [0, 1])
            for (offset = [-snap_tab_width / 2 - snap_slot_width,
                           snap_tab_width / 2])
                translate([x + offset,
                           side == 0 ? -0.1 : outer_width - wall - 0.1,
                           snap_anchor_z])
                    cube([snap_slot_width,
                          wall + 0.2,
                          base_height - snap_anchor_z + 0.2]);
}

module seed_cradle() {
    guide_length = 4;
    guide_width = 0.8;
    guide_height = 1.5;
    for (x = [seed_origin[0] + 6,
              seed_origin[0] + seed_envelope[0] - 10]) {
        translate([x, seed_origin[1] - guide_width, floor])
            cube([guide_length, guide_width, guide_height]);
        translate([x, seed_origin[1] + seed_envelope[1], floor])
            cube([guide_length, guide_width, guide_height]);
    }
    translate([seed_origin[0] + seed_envelope[0],
               seed_origin[1],
               floor])
        cube([guide_width, seed_envelope[1], guide_height]);
}

module button_holder() {
    x0 = button_center[0] - button_body[0] / 2;
    y0 = outer_width - wall - button_body[1] - button_fit_clearance;
    z0 = floor;
    for (x = [x0, x0 + button_body[0] - 2])
        translate([x, y0 - button_holder_wall, z0])
            cube([2, button_holder_wall, button_body[2]]);
    for (x = [x0 - button_holder_wall - button_fit_clearance / 2,
              x0 + button_body[0] + button_fit_clearance / 2])
        translate([x, y0 - button_holder_wall, z0])
            cube([button_holder_wall,
                  button_body[1] + button_holder_wall,
                  2]);
}

module base_shell() {
    difference() {
        rounded_prism([outer_length, outer_width, base_height], corner_radius);
        translate([wall, wall, floor])
            rounded_prism([outer_length - 2 * wall,
                           outer_width - 2 * wall,
                           base_height - floor + 0.1],
                          max(corner_radius - wall, 0.1));
    }
}

module base() {
    difference() {
        union() {
            base_shell();
            snap_nubs();
            seed_cradle();
            button_holder();
        }

        translate([-0.1,
                   usb_center_y - usb_cutout[0] / 2,
                   usb_bottom_z])
            cube([wall + 0.2, usb_cutout[0], usb_cutout[1]]);

        translate([outer_length - wall - 0.1,
                   audio_center_y,
                   audio_center_z])
            rotate([0, 90, 0])
                cylinder(h = wall + 0.2, d = audio_cutout_diameter);

        translate([button_center[0], outer_width + 0.1, button_center[2]])
            rotate([90, 0, 0])
                cylinder(h = wall + 0.2, d = button_actuator_diameter);

        snap_slot_cuts();
    }
}

module lid_skirt() {
    x0 = wall + fit_clearance;
    y0 = wall + fit_clearance;
    rail_length = outer_length - 2 * (wall + fit_clearance);
    union() {
        translate([x0, y0, lid_thickness])
            cube([rail_length, skirt_thickness, skirt_depth]);
        translate([x0,
                   outer_width - wall - fit_clearance - skirt_thickness,
                   lid_thickness])
            cube([rail_length, skirt_thickness, skirt_depth]);
        translate([x0, y0 + skirt_thickness, lid_thickness])
            cube([skirt_thickness,
                  outer_width - 2 * (y0 + skirt_thickness),
                  skirt_depth]);
    }
}

module oled_post_positions() {
    for (x = [-oled_hole_spacing[0] / 2, oled_hole_spacing[0] / 2])
        for (y = [-oled_hole_spacing[1] / 2, oled_hole_spacing[1] / 2])
            translate([oled_center[0] + x, oled_center[1] + y, 0]) children();
}

module trrs_post_positions() {
    for (y = trrs_hole_y)
        translate([trrs_hole_x, y, 0]) children();
}

module mount_post() {
    translate([0, 0, lid_thickness - 0.1])
        cylinder(h = mount_standoff + 0.1, d = mount_post_diameter);
}

module lid_mounts() {
    oled_post_positions() mount_post();
    trrs_post_positions() mount_post();
    for (y = trrs_hole_y)
        translate([trrs_origin[0] + 2.2,
                   y,
                   lid_thickness - 0.1])
            cylinder(h = mount_standoff + 0.1, d = 3);
}

module snap_window_cuts() {
    y0 = wall + fit_clearance;
    for (x = snap_centers) {
        translate([x - 3, y0 - 0.1, 3.15])
            cube([6, skirt_thickness + 0.2, snap_height + 0.1]);
        translate([x - 3,
                   outer_width - wall - fit_clearance - skirt_thickness - 0.1,
                   3.15])
            cube([6, skirt_thickness + 0.2, snap_height + 0.1]);
    }
}

module mount_pilot_cuts() {
    oled_post_positions()
        translate([0, 0, mount_pilot_start])
            cylinder(h = lid_thickness + mount_standoff - mount_pilot_start + 0.2,
                     d = mount_pilot_diameter);
    trrs_post_positions()
        translate([0, 0, mount_pilot_start])
            cylinder(h = lid_thickness + mount_standoff - mount_pilot_start + 0.2,
                     d = mount_pilot_diameter);
}

module lid() {
    difference() {
        union() {
            rounded_prism([outer_length, outer_width, lid_thickness], corner_radius);
            lid_skirt();
            lid_mounts();
        }

        translate([oled_center[0] - oled_window[0] / 2,
                   oled_center[1] - oled_window[1] / 2,
                   -0.1])
            cube([oled_window[0], oled_window[1], lid_thickness + 0.2]);

        snap_window_cuts();
        mount_pilot_cuts();
    }
}

module base_component_preview() {
    color("black") translate(seed_origin) cube(seed_envelope);
    color("darkslategray")
        translate([button_center[0] - button_body[0] / 2,
                   outer_width - wall - button_body[1],
                   floor])
            cube(button_body);
}

module lid_component_preview() {
    color("navy")
        translate([oled_origin[0],
                   oled_origin[1],
                   lid_thickness + mount_standoff])
            cube(oled_board);
    color("royalblue")
        translate([trrs_origin[0],
                   trrs_origin[1],
                   lid_thickness + mount_standoff])
            cube(trrs_board);
}

module position_lid_for_assembly() {
    translate([0, outer_width, base_height + lid_thickness])
        rotate([180, 0, 0]) children();
}

module assembly() {
    color("gainsboro", 0.8) base();
    position_lid_for_assembly() color("whitesmoke", 0.8) lid();
    base_component_preview();
    position_lid_for_assembly() lid_component_preview();
}
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

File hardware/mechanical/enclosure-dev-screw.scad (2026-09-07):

part = "layout"; // "base", "lid", "assembly", or "layout"

$fn = 48;

outer_length = 80;
outer_width = 50;
total_height = 12;
base_thickness = 1.6;
lid_height = total_height - base_thickness;
roof = 1.6;
wall = 1.6;
corner_radius = 3;

case_screw_x = [2.7, outer_length - 2.7];
case_screw_y = [2.7, outer_width - 2.7];
case_boss_diameter = 4.6;
case_pilot_diameter = 1.8;
case_clearance_diameter = 2.8;
case_pilot_start = 3.5;

mount_standoff = 1.2;
component_z = roof + mount_standoff;
mount_post_diameter = 4.8;
mount_pilot_diameter = 1.8;
mount_pilot_floor = 0.4;

seed_envelope = [51.26, 18.24, 6.5];
seed_origin = [2.1, 5.5, component_z];
seed_rear_support_depth = 2;
seed_rear_support_width = 12;
seed_rear_support_height = 5;

oled_board = [33.02, 21.59, 6];
oled_origin = [5.5, 26, component_z];
oled_hole_spacing = [27.94, 16.51];
oled_window = [26, 8.5];
oled_center = [oled_origin[0] + oled_board[0] / 2,
               oled_origin[1] + oled_board[1] / 2];

trrs_board = [17.145, 17.78, 6.5];
trrs_x = outer_length - wall - trrs_board[0] - 0.4;
trrs_origins = [
    [trrs_x, 5.5, component_z],
    [trrs_x, 26.7, component_z]
];
trrs_hole_x_offset = 14.605;
trrs_hole_y_offsets = [2.54, 15.24];

button_size = [6, 6, 6];
button_center = [48, 35.5];
button_body_depth = 3.6;
button_fit_clearance = 0.3;
button_holder_wall = 1;
button_standoff = 0;
button_z = roof + button_standoff;
button_access_diameter = 7;

usb_cutout = [12, 5.5];
usb_center_y = seed_origin[1] + seed_envelope[1] / 2;
usb_center_z = component_z + seed_envelope[2] / 2;
audio_cutout_diameter = 7.5;
audio_center_z = component_z + trrs_board[2] / 2;

module rounded_prism(size, radius) {
    linear_extrude(height = size[2])
        offset(r = radius)
            offset(delta = -radius)
                square([size[0], size[1]]);
}

module case_screw_positions() {
    for (x = case_screw_x)
        for (y = case_screw_y)
            translate([x, y, 0]) children();
}

module oled_post_positions() {
    for (x = [-oled_hole_spacing[0] / 2, oled_hole_spacing[0] / 2])
        for (y = [-oled_hole_spacing[1] / 2, oled_hole_spacing[1] / 2])
            translate([oled_center[0] + x, oled_center[1] + y, 0]) children();
}

module trrs_post_positions() {
    for (origin = trrs_origins)
        for (y_offset = trrs_hole_y_offsets)
            translate([origin[0] + trrs_hole_x_offset,
                       origin[1] + y_offset,
                       0]) children();
}

module lid_shell() {
    difference() {
        rounded_prism([outer_length, outer_width, lid_height], corner_radius);
        translate([wall, wall, roof])
            rounded_prism([outer_length - 2 * wall,
                           outer_width - 2 * wall,
                           lid_height - roof + 0.1],
                          max(corner_radius - wall, 0.1));
    }
}

module case_bosses() {
    case_screw_positions()
        translate([0, 0, roof - 0.1])
            cylinder(h = lid_height - roof + 0.1,
                     d = case_boss_diameter);
}

module component_mount_post() {
    translate([0, 0, roof - 0.1])
        cylinder(h = mount_standoff + 0.1,
                 d = mount_post_diameter);
}

module component_mounts() {
    oled_post_positions() component_mount_post();
    trrs_post_positions() component_mount_post();
}

module seed_guides() {
    guide_length = 3;
    guide_width = 0.7;
    guide_height = mount_standoff + 1.3;
    for (x = [seed_origin[0] + 6,
              seed_origin[0] + seed_envelope[0] - 9]) {
        translate([x,
                   seed_origin[1] - guide_width,
                   roof])
            cube([guide_length, guide_width, guide_height]);
        translate([x,
                   seed_origin[1] + seed_envelope[1],
                   roof])
            cube([guide_length, guide_width, guide_height]);
    }
    translate([seed_origin[0] + seed_envelope[0],
               seed_origin[1]
                   + (seed_envelope[1] - seed_rear_support_width) / 2,
               roof])
        cube([seed_rear_support_depth,
              seed_rear_support_width,
              seed_rear_support_height]);
}

module button_holder() {
    pocket = [button_size[0] + button_fit_clearance,
              button_size[1] + button_fit_clearance];
    x0 = button_center[0] - pocket[0] / 2;
    y0 = button_center[1] - pocket[1] / 2;
    holder_height = button_standoff + button_body_depth + 0.6;
    lip_z = button_z + button_body_depth;

    translate([x0 - button_holder_wall,
               y0 - button_holder_wall,
               roof])
        cube([button_holder_wall,
              pocket[1] + 2 * button_holder_wall,
              holder_height]);
    for (y = [y0 - button_holder_wall, y0 + pocket[1]]) {
        translate([x0, y, roof])
            cube([pocket[0], button_holder_wall, holder_height]);
    }
    translate([x0, y0 - button_holder_wall, lip_z])
        cube([pocket[0], button_holder_wall + 0.8, 0.6]);
    translate([x0, y0 + pocket[1] - 0.8, lip_z])
        cube([pocket[0], button_holder_wall + 0.8, 0.6]);
}

module case_pilot_cuts() {
    case_screw_positions()
        translate([0, 0, case_pilot_start])
            cylinder(h = lid_height - case_pilot_start + 0.2,
                     d = case_pilot_diameter);
}

module component_pilot_cuts() {
    oled_post_positions()
        translate([0, 0, mount_pilot_floor])
            cylinder(h = component_z - mount_pilot_floor + 0.2,
                     d = mount_pilot_diameter);
    trrs_post_positions()
        translate([0, 0, mount_pilot_floor])
            cylinder(h = component_z - mount_pilot_floor + 0.2,
                     d = mount_pilot_diameter);
}

module connector_cuts() {
    translate([-0.1,
               usb_center_y - usb_cutout[0] / 2,
               usb_center_z - usb_cutout[1] / 2])
        cube([wall + 0.2, usb_cutout[0], usb_cutout[1]]);

    for (origin = trrs_origins)
        translate([outer_length - wall - 0.1,
                   origin[1] + trrs_board[1] / 2,
                   audio_center_z])
            rotate([0, 90, 0])
                cylinder(h = wall + 0.2, d = audio_cutout_diameter);
}

module lid() {
    difference() {
        union() {
            lid_shell();
            case_bosses();
            component_mounts();
            seed_guides();
            button_holder();
        }

        translate([oled_center[0] - oled_window[0] / 2,
                   oled_center[1] - oled_window[1] / 2,
                   -0.1])
            cube([oled_window[0], oled_window[1], roof + 0.2]);

        translate([button_center[0], button_center[1], -0.1])
            cylinder(h = roof + 0.2, d = button_access_diameter);

        connector_cuts();
        case_pilot_cuts();
        component_pilot_cuts();
    }
}

module base() {
    difference() {
        rounded_prism([outer_length,
                       outer_width,
                       base_thickness],
                      corner_radius);
        case_screw_positions()
            translate([0, 0, -0.1])
                cylinder(h = base_thickness + 0.2,
                         d = case_clearance_diameter);
    }
}

module component_preview() {
    color("black") translate(seed_origin) cube(seed_envelope);
    color("navy") translate(oled_origin) cube(oled_board);
    for (origin = trrs_origins)
        color("royalblue") translate(origin) cube(trrs_board);
    color("darkslategray")
        translate([button_center[0] - button_size[0] / 2,
                   button_center[1] - button_size[1] / 2,
                   button_z])
            cube(button_size);
}

module position_base_for_assembly() {
    translate([outer_length, 0, total_height])
        rotate([0, 180, 0]) children();
}

module assembly() {
    color("whitesmoke", 0.8) lid();
    position_base_for_assembly()
        color("gainsboro", 0.8) base();
    component_preview();
}

if (part == "base") {
    base();
} else if (part == "lid") {
    lid();
} else if (part == "assembly") {
    assembly();
} else {
    lid();
    translate([0, outer_width + 8, 0]) base();
}

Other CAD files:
hardware/mechanical/old/v0-m4/linerack-enclosure-m4-lid.stl
hardware/mechanical/old/compact-23mm/linerack-enclosure-compact-base.stl
hardware/mechanical/old/linerack-enclosure-dev-friction-lid.stl
hardware/mechanical/old/enclosure-v0.scad
hardware/mechanical/old/compact-20.7mm/enclosure-dev-screw.scad
hardware/mechanical/old/linerack-enclosure-dev-friction-layout.stl
hardware/mechanical/old/linerack-enclosure-dev-screw-base.stl
hardware/mechanical/old/linerack-enclosure-dev-screw-layout.stl
hardware/mechanical/old/linerack-enclosure-dev-screw-lid.stl

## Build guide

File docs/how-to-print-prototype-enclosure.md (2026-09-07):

# How to print the development enclosure

Print and fit-check the current Seed3 development enclosure.

## Prerequisites

- OpenSCAD
- A PLA-capable printer
- Four M2×8 case screws
- Eight M2×4 breakout-board screws

## Render the enclosure

Use `hardware/mechanical/enclosure-dev-screw.scad` for the primary enclosure.
Set `part = "assembly"`, render it, and inspect Seed3, OLED, TRRS, button, and
wire clearance. The current enclosure is 80 × 50 × 12 mm and has not been
fully verified; its revised screw and button clearances remain unprinted.

Set `part = "layout"` to export one STL, or export `base` and `lid` separately.
The current exports are written to `hardware/mechanical/generated/` and use the
`linerack-enclosure-dev-screw-*.stl` filenames. The `assembly` STL is a fit
preview; print the `layout` STL or the separate `base` and `lid` STLs.

## Print and assemble

1. Place the base floor and lid exterior face on the build plate.
2. Print without supports using 0.2 mm layers, three perimeters, and PLA.
3. Confirm M2 screws enter the 1.8 mm pilots without splitting bosses. Stop if
   insertion whitens PLA or requires excessive torque.
4. Mount the OLED and TRRS boards with M2×4 screws.
5. Insulate Seed3 and solder joints, restrain wiring, and keep BOOT and RESET
   reachable by opening the lid.

## Verify the fit

Connect USB and audio while watching the mounted boards. Connectors must align
with their openings without moving a board or loading point-to-point wiring.

See `hardware/mechanical/README.md` for dimensions, output filenames, fit
status, and archived designs. This enclosure does not validate headphone-output
safety, production assembly, or environmental compliance.

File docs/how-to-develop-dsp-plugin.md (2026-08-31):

# How to develop a new DSP plugin

Add a compiled DSP plugin to Seed3 firmware, its HID capability contract, and
the browser configurator. LineRack does not dynamically load executable plugin
code; every device plugin is built into firmware.

## Prerequisites

- A checkout that passes [development setup](how-to-set-up-development.md)
- A stable plugin ID and numeric parameter contract
- A native test signal and measurable expected result
- Seed3 hardware for final playback and resource checks

Read the [DSP and display architecture](dsp-and-display-direction.md) before
adding an algorithm with large state, delay memory, or variable execution time.

## 1. Define the contract

Choose the public contract before implementing the processor:

- Use a stable, kebab-case plugin ID no longer than 19 ASCII bytes.
- Start a new plugin at version `1`. Current firmware rejects other versions.
- Define each parameter's ID, default, minimum, maximum, step, and optional unit.
- Keep the plugin at five parameters or fewer unless you first change
  `LINERACK_MAX_PARAMETERS` and the persisted block layout.
- Append new persisted enum values. Never renumber an existing
  `LineRackBlockType` value.

The CBOR decoder's parameter mask has 16 bits, with 15 parameter IDs currently
assigned. If the plugin needs more than one new parameter ID, expand
`ParameterSlot`, its mask type, and associated tests first. Reuse an existing
parameter ID only when its meaning and unit are identical. The
[HID control protocol](hid-protocol.md) is the authoritative limit reference.

## 2. Implement and test the processor

Add the processor to `firmware/dsp/processor.h`. Follow the existing processor
shape:

- `Configure(...)` calculates coefficients and resets state outside the audio
  callback.
- `Process(float& left, float& right)` updates stereo samples in place.
- State uses fixed storage; processing performs no allocation, I/O, logging, or
  unbounded work.
- Stereo-linked dynamics derive control gain from both channels.

Put large delay lines in external SDRAM rather than inside the processor object.
Both active and staging chains exist during a setup update, so budget state for
two complete worst-case chains.

Add focused cases to `firmware/dsp/processor_test.cpp`. Test bypass-equivalent
settings, expected gain or frequency response, stereo behavior, parameter
extremes, finite output, and decay or stability where applicable. Run:

```sh
make -C firmware/dsp test
```

## 3. Add the persisted block type

Update the firmware model:

1. Append the block type in `firmware/usb/preset_model.h`.
2. Validate every parameter range in `LineRackPresetBankValid()` in
   `firmware/usb/preset_model.c`.
3. Add a valid instance and out-of-range cases to
   `firmware/usb/preset_model_test.c`.
4. Change `LineRackPresetBankDefaults()` only if the plugin belongs in a default
   device preset.

If the change alters `LineRackBlock` or `LineRackPresetBank` size, treat it as a
persistence migration. Existing QSPI records with a different payload size are
rejected, so preserve or explicitly migrate stored setups before shipping the
change.

## 4. Wire the real-time chain

Extend `ChainProcessor` in `firmware/usb_audio.cpp`:

1. Add fixed processor storage for every possible block position.
2. Configure the matching processor in `ChainProcessor::Configure()`.
3. Process it in chain order in `ChainProcessor::Process()`.
4. Add external workspaces beside `reverb_memory` when the processor needs
   large state.

The enabled flag is handled by the chain. Do not add plugin-specific bypass
state unless the algorithm needs a click-safe transition.

If the plugin changes frequency response, extend `BlockMagnitudeDb()` in
`firmware/usb/display_model.c` and its cases in
`firmware/usb/display_model_test.c`. Otherwise the device's EQ Response mode
will omit the plugin.

## 5. Extend HID capabilities and preset CBOR

Update `firmware/usb/preset_cbor.cpp` in each of these places:

- Increase the `plugins` array count in `Capabilities()`.
- Emit one `PluginDefinition()` and its `NumberParameter()` entries.
- Encode parameters in `Parameters()`.
- Map the block type in `PluginId()`.
- Add new names to `ParameterSlot` and `FindParameter()`.
- Decode the exact parameter mask and block fields in `DecodePlugin()`.

Extend `firmware/usb/preset_cbor_test.cpp` with capability discovery and preset
round-trip coverage. Keep missing, duplicate, unknown, and out-of-range values
rejected. Run:

```sh
make -C firmware/usb test
```

## 6. Add browser support

Add the same contract to `pluginCatalog` in `src/presets.ts`. This catalogue
drives the simulator; attached hardware remains authoritative through its HID
capability response. The generic editor renders numeric parameters without a
plugin-specific component.

Add three to ten useful parameter presets in `src/effect-presets.ts`. The
existing effect-preset test enforces their count, uniqueness, parameter set,
range, and step alignment.

If the plugin changes frequency response, add its response calculation in
`src/eq.ts` and include its ID in the response sets in `src/eq-editor.tsx` and
`src/App.tsx`. Add a custom editor only when generic numeric sliders cannot
represent the contract.

Update affected tests in `src/presets.test.ts`, `src/effect-presets.test.ts`,
and `src/eq.test.ts`. Add listening recipes in `src/preset-library.ts` only when
the new plugin improves a complete preset.

## 7. Verify the complete implementation

Run all repository gates:

```sh
make lint
make check
make test
make build
```

Confirm the composite image remains within the 126,976-byte flash gate. Do not
raise the gate to make the plugin fit.

Flash Seed3 and verify the plugin with real program audio:

1. Confirm `Hello` advertises the plugin and exact parameter contract.
2. Add, configure, reorder, bypass, remove, apply, and reload the plugin.
3. Test multiple instances and a worst-case ten-block chain.
4. Apply parameter and structural changes during playback.
5. Confirm USB packet count advances and underrun/overrun counters remain zero.
6. For a frequency-shaping plugin, confirm OLED EQ Response includes it.
7. Power-cycle and confirm the setup reloads.

Update the plugin table in [HID control protocol](hid-protocol.md) after the
device and browser checks pass.

## Related documentation

- [DSP and display architecture](dsp-and-display-direction.md)
- [HID control protocol](hid-protocol.md)
- [Preset file format](preset-file-format.md)
- [Firmware build targets](firmware-build-targets.md)
- [Verify USB Audio on Seed3](usb-audio-bring-up.md)

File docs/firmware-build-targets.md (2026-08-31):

# Firmware build targets

Seed3 firmware targets share the `firmware/build` directory. Run `clean` with
the target you are leaving before switching Makefiles:

```sh
make -C firmware -f Makefile.output-test clean
make -C firmware -f Makefile.usb-composite
```

Build a target with `make -C firmware -f <makefile>`. Add `program-dfu` to flash
an attached Seed3 already in DFU mode.

| Makefile | Image | Purpose |
| --- | --- | --- |
| `Makefile` | `linerack` | Legacy analog pass-through with button-selected OLED slot number |
| `Makefile.diagnostics` | `diagnostics` | Board-only LED diagnostic; no peripheral wiring required |
| `Makefile.output-test` | `output_test` | 440 Hz left and 660 Hz right codec-output tones |
| `Makefile.dsp-demo` | `dsp_demo` | Generated stereo tones through four Gain and Limiter settings |
| `Makefile.eq-demo` | `eq_demo` | Generated stereo tones through four Parametric EQ settings |
| `Makefile.headless` | `headless` | Analog stereo pass-through and LED slot feedback without OLED or USB control |
| `Makefile.usb-audio` | `usb_audio` | USB Audio playback without the WebHID composite interface |
| `Makefile.usb-composite` | `usb_composite` | Current integrated USB Audio, DSP, WebHID, storage, button, and OLED firmware |

`Makefile.usb-composite` is the release-development target and enforces the
126,976-byte internal-flash limit. Other images are diagnostics; they do not
define current device behavior or preset compatibility.

See [Build and verify the Seed3 prototype](prototype-bring-up.md)
for the ordered board, output, and integrated-image workflow.

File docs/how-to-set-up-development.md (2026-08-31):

# How to set up LineRack development

Prepare a checkout for web development, native tests, and Seed3 firmware builds.

## Prerequisites

- Node.js 22 or newer
- pnpm 11.9
- GNU Make and Git
- Arm GNU embedded toolchain and `dfu-util` for firmware work

On macOS, install the firmware tools with Homebrew:

```sh
brew install --cask gcc-arm-embedded
brew install dfu-util
```

## Install dependencies

Clone the repository and install web dependencies:

```sh
git clone https://github.com/1kbgz/linerack.git
cd linerack
pnpm install --frozen-lockfile
```

Fetch the pinned libDaisy revision and build it:

```sh
make develop-firmware
```

The dependency is stored in the ignored `.deps/libDaisy` directory. The
Makefile will not change its revision when that checkout contains local changes.

## Verify the checkout

Run the complete repository lifecycle:

```sh
make lint
make check
make test
make build
```

`make test` runs browser, accessibility, native DSP, USB, display, persistence,
and protocol tests. `make build` creates the static site in `dist` and builds
the composite Seed3 firmware in `firmware/build`.

The firmware build enforces a 126,976-byte internal-flash limit. Do not raise
the limit to make a build pass; move the firmware to the supported
libDaisy bootloader/SRAM path first.

## Run the configurator

Start the development server:

```sh
pnpm dev
```

Open the printed origin at `/configure` in desktop Chrome to use WebHID with
attached hardware. Other browsers can use the simulator.

## Flash the composite firmware

Download any setup that must survive a preset-schema change. Enter DFU by
holding **BOOT**, pressing and releasing **RESET**, then releasing **BOOT**.
Flash the current integrated image:

```sh
make -C firmware -f Makefile.usb-composite program-dfu
```

`dfu-util` 0.11 can report `Error during download get_status` after a successful
transfer because Seed3 disconnects while leaving DFU. Confirm success by
checking that USB Audio and WebHID enumerate again.

## Related documentation

- [Build and verify the Seed3 prototype](prototype-bring-up.md)
- [Update from the repository template](how-to-update-template.md)
- [Firmware build targets](firmware-build-targets.md)
- [Verify USB Audio on Seed3](usb-audio-bring-up.md)

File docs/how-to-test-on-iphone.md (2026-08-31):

# How to test LineRack on iPhone

Verify class-compliant USB audio playback and bus power on a USB-C iPhone.
Mobile configuration is outside the current scope; configure LineRack from
desktop Chrome first.

## Prerequisites

- A USB-C iPhone
- A known USB-C data cable
- A LineRack prototype that passes desktop USB Audio verification
- Two stored presets with clearly different sound

Start with low listening volume.

## Verify the stored setup

On a desktop, confirm that:

1. LineRack appears as a stereo audio output.
2. Program audio reaches both channels.
3. A quick button double-press changes the active preset and its sound.
4. The setup survives one USB power cycle.

## Test playback and power

Disconnect LineRack from the desktop and connect it directly to the iPhone. Do
not use an unpowered hub. If iOS asks whether the device is **Headphones** or
**Other**, choose **Headphones**.

Play a familiar stereo track and confirm that:

1. iOS routes audio to LineRack instead of its speakers.
2. LineRack remains powered without another supply.
3. Left and right channels are correctly mapped.
4. Pitch and speed remain stable for at least five minutes.
5. A quick button double-press changes presets without interrupting playback.
6. iPhone volume changes output level and briefly appears on the OLED.

iOS Safari does not provide the WebHID transport used by the configurator, so
browser configuration is not part of this test.

## Verify reconnect behavior

While audio is playing, disconnect USB, wait five seconds, and reconnect.
Resume playback if iOS paused it. LineRack should enumerate without a reset or
DFU cycle.

Reconnect LineRack to the desktop afterward. Confirm USB Audio and WebHID both
enumerate and stored presets remain intact.

## Troubleshoot missing audio

1. Confirm iOS still shows LineRack as the active route.
2. Try another known data cable.
3. Remove hubs and adapters.
4. Verify the same preset and output jack on a desktop.
5. Reflash the last verified composite image only if desktop playback also
   fails.

An iOS Simulator cannot test USB enumeration, power, audio routing, or timing.
Use physical hardware for every result in this guide.

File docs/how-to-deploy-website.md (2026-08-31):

# How to deploy the website

Deploy the tested static site to the production Cloudflare Pages project using
the repository workflow.

## Prerequisites

- A checkout prepared through [development setup](how-to-set-up-development.md)
- Playwright Chromium installed with `pnpm exec playwright install chromium`
- The `linerack` Pages project and `linerack.dev` domain provisioned by the
  `1kbgz/terraform` repository
- Repository variable `CLOUDFLARE_ACCOUNT_ID`
- Repository secret `CLOUDFLARE_API_TOKEN` with Cloudflare Pages edit access
- A pull request whose web and firmware checks pass

Store credential values only in the GitHub repository settings or the approved
infrastructure secret store. Never put values in documentation, source,
workflow arguments, pull requests, or logs.

## Validate the site artifact

Run the same repository gates required by CI:

```sh
make lint
make check
make test-web
make build-web
```

The static site should exist under `dist`. CI separately tests and builds
firmware before allowing production deployment.

## Deploy from `main`

Merge the reviewed change into `main`. `.github/workflows/build.yaml` runs the
web and firmware jobs, downloads the tested site artifact, and sends `dist` to
the existing `linerack` Pages project through Wrangler Direct Upload.

The deploy job runs only when both build jobs pass, the ref is `main`, and
`CLOUDFLARE_ACCOUNT_ID` is configured. A protected `production` GitHub
environment may also require approval. Pull requests and other branches do not
deploy.

To repeat a deployment without changing source, dispatch **Build Status** on
the `main` branch from GitHub Actions.

## Verify production

After the deploy job passes, check:

1. `https://linerack.dev/`
2. `https://linerack.dev/configure`
3. `https://linerack.dev/docs`
4. One direct documentation deep link

Confirm the landing page loads, the configurator enters simulator mode without
hardware, the developer-doc index contains every section, and a deep-link
refresh returns the requested page instead of a 404.

## Troubleshoot a skipped deploy

Check the workflow ref, the `CLOUDFLARE_ACCOUNT_ID` repository variable, and
whether the `production` environment is waiting for approval. A missing
variable intentionally skips deployment. Do not print the API token while
diagnosing credentials.

See [Web deployment reference](deployment-reference.md) for routes, workflow
ownership, Pages settings, and credential names.

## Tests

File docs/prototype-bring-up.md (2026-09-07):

# Build and verify the Seed3 prototype

This tutorial builds one working LineRack prototype, from an unwired Seed3 to
USB Audio playback, browser configuration, physical control, and OLED output.

## Before you start

Complete [Set up LineRack development](how-to-set-up-development.md).
Keep the [prototype hardware reference](prototype-hardware-reference.md)
open for the verified parts list, pinout, and electrical limits.

Use powered speakers or an audio-interface line input at minimum volume for
initial output tests. Direct headphone testing does not establish a safe load,
clean output level, or short-circuit limit.

## 1. Verify the unwired Seed3

Leave all peripherals disconnected. Enter DFU by holding **BOOT**, pressing and
releasing **RESET**, then releasing **BOOT**. Flash the board diagnostic:

```sh
dfu-util --list
make -C firmware -f Makefile.diagnostics program-dfu
```

The onboard LED should blink twice per second. Press and release **RESET** once
if it does not start after flashing.

`dfu-util` 0.11 on macOS may report `Error during download get_status` after
`File downloaded successfully`. Treat the transfer as successful only when the
expected firmware behavior follows.

## 2. Wire the prototype

Disconnect USB power. Wire the button, OLED, and stereo output exactly as shown
in the [prototype hardware reference](prototype-hardware-reference.md).
Use Seed3's printed pin labels, not breadboard row numbers.

Inspect solder joints and confirm no power rail is shorted to ground before
reconnecting USB.

## 3. Verify stereo output

Enter DFU and flash the output diagnostic:

```sh
make -C firmware -f Makefile.output-test program-dfu
```

The onboard LED should remain solid. The output should carry a quiet 440 Hz
tone on the left and 660 Hz tone on the right, each near -30 dBFS. Confirm both
channels and their mapping before continuing.

## 4. Flash the integrated firmware

Download the current setup before flashing firmware that changes
`LineRackPresetBank`. QSPI records with a different payload size are rejected
and replaced with defaults.

Enter DFU again, then build and flash the composite image:

```sh
make -C firmware -f Makefile.usb-composite clean
make -C firmware -f Makefile.usb-composite -j4
make -C firmware -f Makefile.usb-composite program-dfu
```

The host should list `LineRack USB Audio Dev` as a two-channel, 48 kHz output.
Select it, start familiar program audio at low volume, and confirm clean left
and right playback.

## 5. Connect the configurator

Run the local site with `pnpm dev`, open its origin at `/configure` in desktop
Chrome, and select the LineRack device when prompted. The configurator should
report hardware editing instead of simulator editing.

Change one audible parameter and apply the setup. Playback should continue and
the effect should change without a USB reconnect.

## 6. Verify physical controls and display

Check each user-facing interaction:

1. Single-press the button. The OLED should wake.
2. Quickly double-press it. The active preset should advance and briefly appear
   on both the OLED and browser preview.
3. Hold it for 3 seconds. The persistent display mode should cycle immediately
   among Preset, EQ Response, and Visualizer without waiting for release.
4. Change host volume. The OLED should show the new percentage temporarily.
5. Apply another browser edit. The OLED should wake.

## 7. Verify persistence

Rename a preset, apply the setup, and disconnect USB for five seconds. Reconnect
the device and confirm the name, effect values, display settings, and active
preset reload.

You now have a complete development prototype. Continue with the focused
[USB Audio verification](usb-audio-bring-up.md),
[iPhone test](how-to-test-on-iphone.md), or
[development enclosure guide](how-to-print-prototype-enclosure.md).

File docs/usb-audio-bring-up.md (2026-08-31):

# How to verify USB Audio on Seed3

Verify playback, clock recovery, DSP, HID traffic, host volume, and reconnect
behavior on the integrated Seed3 firmware.

## Prerequisites

- A prototype that completed the [Seed3 tutorial](prototype-bring-up.md)
- A desktop host and known stereo test material
- Current firmware dependencies from `make develop-firmware`
- Powered speakers or an audio-interface line input at low volume

## Build and flash

Enter DFU and flash the composite Audio + HID image:

```sh
make -C firmware -f Makefile.usb-composite clean
make -C firmware -f Makefile.usb-composite -j4
make -C firmware -f Makefile.usb-composite program-dfu
```

The expected playback format is USB Audio Class 1, stereo, signed 16-bit PCM at
a fixed 48 kHz sample rate. The device is bus powered and exposes master volume
and mute controls. It has no capture endpoint or sample-rate switching.

## Verify enumeration and playback

Select `LineRack USB Audio Dev` as the host output. On macOS, inspect the device
with:

```sh
system_profiler SPAudioDataType
```

Play familiar stereo material and verify:

1. Left and right channels are correctly mapped.
2. Playback has no ticks, gaps, speed drift, or pitch drift.
3. Host volume and mute change the analog output.
4. The OLED briefly displays host volume as a percentage.
5. Distinct presets remain audible while switching slots.

## Verify stream diagnostics

Connect through desktop Chrome and expand **Global**, then **Diagnostics**.
During playback:

- `usbPackets` should increase continuously.
- `bufferFillFrames` should remain bounded near its operating target.
- `underruns` and `overruns` should remain zero.

Run playback for at least 30 minutes. The firmware reconciles independent USB
and codec clocks with bounded adaptive resampling; a ring buffer alone cannot
prevent eventual underflow or overflow.

## Exercise DSP and HID together

Keep audio playing while you:

1. Read the stored setup.
2. Apply at least six parameter changes.
3. Activate each preset from the browser.
4. Change presets with the physical button.
5. Exercise gain, filters, compressor, reverb, and limiter.

Audio should continue without a disconnect, buffer error, or stale browser
state. Power-cycle USB and confirm the applied setup reloads.

## Exercise host state changes

Verify stop and start, cable removal, reconnect, and host sleep and wake. After
each transition, confirm that USB Audio and WebHID return without reflashing or
entering DFU.

Repeat the playback test on Windows and Linux when those hosts are available.
Use the separate [iPhone test](how-to-test-on-iphone.md) for mobile playback.

## Troubleshoot zero output

If the device enumerates but produces no sound:

1. Confirm the global source mode is **USB** and USB trim is `0 dB`.
2. Confirm the host output route, volume, and mute state.
3. Check Diagnostics. A stationary `usbPackets` counter means the host is not
   sending audio; increasing packets with zero output points later in the path.
4. Quit audio-routing software such as SoundSource and test direct playback.
5. Select another host output, disconnect LineRack for ten seconds, reconnect,
   and select it again.
6. Press Seed3 **RESET** and repeat direct playback.
7. Reflash only after the same failure occurs without third-party routing
   software.

Older builds reused one serial and device release across descriptor changes,
which could leave macOS with a stale route. Current firmware derives the serial
from the STM32 unique ID and changes `bcdDevice` when descriptors change.

## Success criteria

- Host selects LineRack without a custom driver.
- Both channels remain correctly mapped.
- Ring-buffer fill stays bounded with zero underruns and overruns.
- DSP changes and HID traffic do not interrupt playback.
- Host volume, mute, disconnect, and reconnect work without reflashing.

Development firmware uses the temporary USB identity `CAFE:4C52`. Production
hardware requires an owned or allocated VID/PID.

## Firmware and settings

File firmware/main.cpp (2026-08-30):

#include "daisy_seed.h"
#include "dev/oled_ssd130x.h"

using namespace daisy;

namespace
{
constexpr uint8_t kSlotCount = 4;

DaisySeed hardware;
Switch preset_button;
OledDisplay<SSD130xI2c128x32Driver> display;
uint8_t active_slot = 1;

void AudioCallback(AudioHandle::InputBuffer input,
                   AudioHandle::OutputBuffer output,
                   size_t                    size)
{
    for(size_t sample = 0; sample < size; ++sample)
    {
        output[0][sample] = input[0][sample];
        output[1][sample] = input[1][sample];
    }
}

void DrawActiveSlot()
{
    const char label[] = {static_cast<char>('0' + active_slot), '\0'};
    display.Fill(false);
    display.SetCursor(58, 7);
    display.WriteString(label, Font_11x18, true);
    display.Update();
}
} // namespace

int main()
{
    hardware.Init();

    preset_button.Init(seed::D10);

    OledDisplay<SSD130xI2c128x32Driver>::Config display_config;
    auto& i2c = display_config.driver_config.transport_config.i2c_config;
    i2c.periph = I2CHandle::Config::Peripheral::I2C_1;
    i2c.speed = I2CHandle::Config::Speed::I2C_400KHZ;
    i2c.pin_config.scl = seed::D11;
    i2c.pin_config.sda = seed::D12;
    display_config.driver_config.transport_config.i2c_address = 0x3c;
    display.Init(display_config);
    DrawActiveSlot();

    hardware.StartAudio(AudioCallback);

    while(true)
    {
        preset_button.Debounce();
        if(preset_button.RisingEdge())
        {
            active_slot = active_slot % kSlotCount + 1;
            DrawActiveSlot();
        }
        System::Delay(1);
    }
}

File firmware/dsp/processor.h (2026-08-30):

#pragma once

#include <algorithm>
#include <cstddef>
#include <cmath>
#include <cstdint>

namespace linerack
{
namespace dsp
{
inline float DbToLinear(float decibels)
{
    return std::pow(10.0f, decibels / 20.0f);
}

class Gain
{
  public:
    void SetGainDb(float decibels) { multiplier_ = DbToLinear(decibels); }

    void Process(float& left, float& right) const
    {
        left *= multiplier_;
        right *= multiplier_;
    }

  private:
    float multiplier_ = 0.0f;
};

class Biquad
{
  public:
    void Configure(float b0, float b1, float b2, float a1, float a2)
    {
        b0_ = b0;
        b1_ = b1;
        b2_ = b2;
        a1_ = a1;
        a2_ = a2;
        Reset();
    }

    void Reset()
    {
        left_ = {};
        right_ = {};
    }

    void Process(float& left, float& right)
    {
        left = ProcessSample(left, left_);
        right = ProcessSample(right, right_);
    }

  private:
    struct State
    {
        float z1 = 0.0f;
        float z2 = 0.0f;
    };

    float ProcessSample(float input, State& state) const
    {
        const float output = b0_ * input + state.z1;
        state.z1 = b1_ * input - a1_ * output + state.z2;
        state.z2 = b2_ * input - a2_ * output;
        return output;
    }

    float b0_ = 0.0f;
    float b1_ = 0.0f;
    float b2_ = 0.0f;
    float a1_ = 0.0f;
    float a2_ = 0.0f;
    State left_;
    State right_;
};

class ParametricEq
{
  public:
    void Configure(float frequency_hz,
                   float gain_db,
                   float q,
                   float sample_rate)
    {
        constexpr float kPi = 3.141592654f;
        const float amplitude = DbToLinear(gain_db * 0.5f);
        const float omega = 2.0f * kPi * frequency_hz / sample_rate;
        const float alpha = std::sin(omega) / (2.0f * q);
        const float cosine = std::cos(omega);
        const float a0 = 1.0f + alpha / amplitude;

        filter_.Configure((1.0f + alpha * amplitude) / a0,
                          (-2.0f * cosine) / a0,
                          (1.0f - alpha * amplitude) / a0,
                          (-2.0f * cosine) / a0,
                          (1.0f - alpha / amplitude) / a0);
    }

    void Reset() { filter_.Reset(); }

    void Process(float& left, float& right) { filter_.Process(left, right); }

  private:
    Biquad filter_;
};

enum class PassFilterMode
{
    HighPass,
    LowPass,
};

class PassFilter
{
  public:
    void Configure(PassFilterMode mode,
                   float          cutoff_hz,
                   float          slope_db_per_octave,
                   float          sample_rate)
    {
        stage_count_ = slope_db_per_octave >= 24.0f ? 2U : 1U;
        if(stage_count_ == 2U)
        {
            ConfigureStage(filters_[0], mode, cutoff_hz, 0.541196f, sample_rate);
            ConfigureStage(filters_[1], mode, cutoff_hz, 1.306563f, sample_rate);
        }
        else
            ConfigureStage(filters_[0], mode, cutoff_hz, 0.70710678f, sample_rate);
    }

    void Process(float& left, float& right)
    {
        for(uint8_t stage = 0U; stage < stage_count_; ++stage)
            filters_[stage].Process(left, right);
    }

  private:
    static void ConfigureStage(Biquad&        filter,
                               PassFilterMode mode,
                               float          cutoff_hz,
                               float          q,
                               float          sample_rate)
    {
        constexpr float kPi = 3.141592654f;
        const float omega = 2.0f * kPi * cutoff_hz / sample_rate;
        const float cosine = std::cos(omega);
        const float alpha = std::sin(omega) / (2.0f * q);
        const float a0 = 1.0f + alpha;
        const bool high_pass = mode == PassFilterMode::HighPass;
        const float b0 = ((high_pass ? 1.0f + cosine : 1.0f - cosine) * 0.5f) / a0;
        const float b1 = (high_pass ? -(1.0f + cosine) : 1.0f - cosine) / a0;
        filter.Configure(b0,
                         b1,
                         b0,
                         (-2.0f * cosine) / a0,
                         (1.0f - alpha) / a0);
    }

    Biquad filters_[2];
    uint8_t stage_count_ = 0U;
};

class NoiseGate
{
  public:
    void Configure(float threshold_db,
                   float attack_ms,
                   float hold_ms,
                   float release_ms,
                   float range_db,
                   float sample_rate)
    {
        threshold_ = DbToLinear(threshold_db);
        floor_ = DbToLinear(range_db);
        attack_coefficient_ = TimeCoefficient(attack_ms, sample_rate);
        release_coefficient_ = TimeCoefficient(release_ms, sample_rate);
        hold_samples_ = static_cast<uint32_t>(hold_ms * 0.001f * sample_rate);
        Reset();
    }

    void Reset()
    {
        gain_ = 1.0f;
        hold_remaining_ = 0U;
    }

    void Process(float& left, float& right)
    {
        const float peak = std::max(std::fabs(left), std::fabs(right));
        float target = floor_;
        if(peak >= threshold_)
        {
            hold_remaining_ = hold_samples_;
            target = 1.0f;
        }
        else if(hold_remaining_ > 0U)
        {
            --hold_remaining_;
            target = 1.0f;
        }
        const float coefficient = target > gain_ ? attack_coefficient_
                                                  : release_coefficient_;
        gain_ = coefficient * gain_ + (1.0f - coefficient) * target;
        left *= gain_;
        right *= gain_;
    }

  private:
    static float TimeCoefficient(float milliseconds, float sample_rate)
    {
        const float samples = milliseconds * 0.001f * sample_rate;
        return samples > 0.0f ? std::exp(-1.0f / samples) : 0.0f;
    }

    float threshold_ = 0.0f;
    float floor_ = 0.0f;
    float attack_coefficient_ = 0.0f;
    float release_coefficient_ = 0.0f;
    float gain_ = 0.0f;
    uint32_t hold_samples_ = 0U;
    uint32_t hold_remaining_ = 0U;
};
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

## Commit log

2026-09-06 Add 12 mm development enclosure
    [dev.csv, enclosure-dev-friction.scad, enclosure-dev-screw.scad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]
2026-09-07 Update prototype firmware and enclosure
    [dev.csv, enclosure-dev-screw.scad, linerack-enclosure-dev-friction-base.stl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]
2026-09-07 Strengthen Seed3 rear support
    [enclosure-dev-screw.scad, linerack-enclosure-dev-screw-assembly.stl, linerack-enclosure-dev-screw-base.stl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]
